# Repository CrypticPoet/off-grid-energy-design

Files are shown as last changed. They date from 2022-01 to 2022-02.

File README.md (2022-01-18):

# Off Grid Energy Design

This repository is for documentation of the Off Grid Energy system design process.

## Process Roadmap

-   [x] Requirements
-   [ ] Specifications
-   [ ] Design

### Specification Components Checklist
- [x] Solar Panels
- [x] Batteries
- [x] Inverter
- [x] Solar Charge Controller
- [x] Solar Panel Mounts
- [x] Battery Monitor
- [x] Backup Generator
- [x] Biogas Plant
- [x] Safety Measures
- [x] Connecting Wires

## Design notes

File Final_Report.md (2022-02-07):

---
title: "Sunergy Final Report"
author: "Tribe E (EE > MT)"
keywords:
   - renewable
   - solar
   - off-grid
   - sustainable
---

# ELP305 Design and Systems Laboratory
## Semester 2, 2021-2022 
### Tribe E

# SUNERGY: Final Report

| ID | v4.0 |
| :--- | :--- |
| Tribe | Tribe E |
| Approved By | Vishal Asthana (TC) / 01-02-2022 / 2200 Hrs |
| Contact for Queries | Mihir Okte (mt1190703@iitd.ac.in) |
| Submitted to | Prof. Subrat Kar, Course Coordinator \| ELP305: Design and Systems Laboratory |
| Date of Submission  | 02-02-2022 |

**NOTE:** The GitHub repository that our tribe is using is linked [here](https://github.com/CrypticPoet/off-grid-energy-design)

## Table of Contents
- [1. Authors](#1-authors)
- [2. Documentation Statistics](#2-documentation-statistics)
	- [2.0.1. Text Statistics](#201-text-statistics)
	- [2.0.2. Readability indices](#202-readability-indices)
- [3. Preamble](#3-preamble)
	- [3.0.1. List of Abbreviations](#301-list-of-abbreviations)
	- [3.0.2. List of Tables](#302-list-of-tables)
	- [3.0.3. List of Figures](#303-list-of-figures)
- [4. Abstract](#4-abstract)
- [5. Aim](#5-aim)
- [6. Scope](#6-scope)
- [7. Requirements](#7-requirements)
	- [7.1. Base Setup](#71-base-setup)
	- [7.2. Basic Requirements](#72-basic-requirements)
	- [7.3. Technical Requirements](#73-technical-requirements)
- [8. Specifications](#8-specifications)
	- [8.1. Electrical Specifications](#81-electrical-specifications)
		- [8.1.1. Battery](#811-battery)
			- [8.1.1.1. Luminous Red Charge RC 18000 150 Ah Battery](#8111-luminous-red-charge-rc-18000-150-ah-battery)
		- [8.1.2. Backup Generator](#812-backup-generator)
		- [8.1.3. Hybrid Solar Inverter (Built in Solar Charge Controller)](#813-hybrid-solar-inverter-built-in-solar-charge-controller)
			- [8.1.3.1. 3KVA/ 36 V Off Grid Solar Inverter](#8131-3kva-36-v-off-grid-solar-inverter)
		- [8.1.4. Solar Charge Controller](#814-solar-charge-controller)
			- [8.1.4.1. Sizing](#8141-sizing)
		- [8.1.5. High Efficiency Solar Panels](#815-high-efficiency-solar-panels)
		- [8.1.6. Wires](#816-wires)
			- [8.1.6.1. Solar DC Cable](#8161-solar-dc-cable)
			- [8.1.6.2. Household connection wires](#8162-household-connection-wires)
		- [8.1.7. Safety Measures](#817-safety-measures)
			- [8.1.7.1. AC Circuit Breaker](#8171-ac-circuit-breaker)
			- [8.1.7.2. DC Circuit Breaker](#8172-dc-circuit-breaker)
			- [8.1.7.3. DC Surge Protection Device](#8173-dc-surge-protection-device)
			- [8.1.7.4. Porcelain Fuse](#8174-porcelain-fuse)
		- [8.1.8. MC4 Connectors](#818-mc4-connectors)
			- [8.1.8.1. MC4 Solar Panel Connectors](#8181-mc4-solar-panel-connectors)
			- [8.1.8.2. 4 in 1 T4 Connector](#8182-4-in-1-t4-connector)
	- [8.2. Mechanical Specifications](#82-mechanical-specifications)
		- [8.2.1. Solar Panel Mounts](#821-solar-panel-mounts)
- [9. Design](#9-design)
	- [9.1. CAD/Assembly](#91-cadassembly)
	- [9.2. Wiring Diagram](#92-wiring-diagram)
- [10. Cost Analysis](#10-cost-analysis)
- [11. Reuse of Materials](#11-reuse-of-materials)
- [12. Project Management](#12-project-management)
	- [12.1. Gantt Chart and CPM](#121-gantt-chart-and-cpm)
	- [12.2. Resources Chart](#122-resources-chart)
	- [12.3. Work Packages](#123-work-packages)
- [13. Attributions](#13-attributions)
- [14. References](#14-references)

---

## 1. Authors
| S. No. | Name | Email id | Role | Performance |
| -----: | :--- | :---: | :--- | :---: |
| 1. | Vishal Asthana | ee1191083@iitd.ac.in | Tribe Coordinator | 1.0 |
| 2. | Ritvik Gupta | mt1190512@iitd.ac.in | Documentation Sub Tribe Coordinator | 1.0 |
| 3. | Shubham Jangra | ee1190529@iitd.ac.in | Solar Panels Sub Tribe Coordinator | 1.0 |
| 4. | Shailendra Thenua | ee1190522@iitd.ac.in | Battery and Inverter Sub Tribe Coordinator | 1.0 |
| 5. | Mihir Okte | mt1190703@iitd.ac.in | CAD Design Sub Tribe Coordinator | 1.0 |
| 6. | Shloka Bhuwalka | ee1190527@iitd.ac.in | Wiring and LTSpice Sub Tribe Coordinator | 1.0 |
| 7. | Uddhav Goel | ee1190540@iitd.ac.in | Project Management Sub Tribe Coordinator | 1.0 |
| 8. | Abhishek Kumar | ee1190456@iitd.ac.in | Member | 1.0 |
| 9. | Abhishek Kumar | ee1190457@iitd.ac.in | Member | 1.0 |
| 10. | Aditya Verma | mt1190672@iitd.ac.in | Member | 0.8 |
| 11. | Ahsan Kamal | mt6190740@iitd.ac.in | Member | 1.0 |
| 12. | Akash Agrawal | ee3190006@iitd.ac.in | Member | 1.0 |
| 13. | Aman Yadav | mt1200786@iitd.ac.in | Member | 0.6 |
| 14. | Amit Kumar | mt6190744@iitd.ac.in | Member | 1.0 |
| 15. | Anirudh Singh Chauhan | ee1191072@iitd.ac.in | Member | 1.0 |
| 16. | Ankit Kumar Meena | ee3190555@iitd.ac.in | Member | 1.0 |
| 17. | Anshuman Panda | mt1190463@iitd.ac.in | Member | 1.0 |
| 18. | Anurag Sharma | mt6190745@iitd.ac.in | Member | 1.0 |
| 19. | Ayush Joshi | ee1190486@iitd.ac.in | Member | 1.0 |
| 20. | Ayush Meena | ee1190468@iitd.ac.in | Member | 0.6 |
| 21. | Bhargav Halipeth | ee3190562@iitd.ac.in | Member | 1.0 |
| 22. | Govind Patidar | ee1190478@iitd.ac.in | Member | 0.0 |
| 23. | Guruvu Surya Sai Prakash | ee1190481@iitd.ac.in | Member | 1.0 |
| 24. | Harshit Nekela | mt1190693@iitd.ac.in | Member | 1.0 |
| 25. | Het Patel | ee1190484@iitd.ac.in | Member | 1.0 |
| 26. | Manisha Chaudhary | ee1190494@iitd.ac.in | Member | 1.0 |
| 27. | Mohit Yadav | ee3190582@iitd.ac.in | Member | 0.5 |
| 28. | Ohm V | ee1190499@iitd.ac.in | Member | 1.0 |
| 29. | Pragya Dhakar | mt6190756@iitd.ac.in | Member | 1.0 |
| 30. | Prasoon Bajpai | mt6190824@iitd.ac.in | Member | 1.0 |
| 31. | Prateek Sinha | mt1190716@iitd.ac.in | Member | 1.0 |
| 32. | Rajdeep Das | mt1190718@iitd.ac.in | Member | 1.0 |
| 33. | Ronak Choudhary | ee3190597@iitd.ac.in | Member | 1.0 |
| 34. | Sahil Raj | mt1190723@iitd.ac.in | Member | 1.0 |
| 35. | Satyam Sharma | ee1190521@iitd.ac.in | Member | 0.5 |
| 36. | Shashank Nehra | ee1190523@iitd.ac.in | Member | 1.0 |
| 37. | Shivam Garg | ee1190600@iitd.ac.in | Member | 1.0 |
| 38. | Shivam Gupta | ee1190601@iitd.ac.in | Member | 1.0 |
| 39. | Shivang Garde | ee1180501@iitd.ac.in | Member | 1.0 |
| 40. | Shivani Singh | ee1190525@iitd.ac.in | Member | 1.0 |
| 41. | Siddhant Sharma | ee1190531@iitd.ac.in | Member | 1.0 |
| 42. | Suvam Paul | ee1190536@iitd.ac.in | Member | 1.0 |
| 43. | Tanmay Kumar | ee1190538@iitd.ac.in | Member | 1.0 |
| 44. | Tushar Singh | ee1190539@iitd.ac.in | Member | 1.0 |
| 45. | Udit Dahiya | ee3190852@iitd.ac.in | Member | 1.0 |
| 46. | Vaibhav Verma | ee1190543@iitd.ac.in | Member | 1.0 |
| 47. | Vansh Gupta | ee1190143@iitd.ac.in | Member | 1.0 |
| 48. | Yash Pal Singh | ee1190548@iitd.ac.in | Member | 1.0 |
| 49. | Yug Garg | ee3190607@iitd.ac.in | Member | 1.0 |

**Table 1:** List of Authors

---

## 2. Documentation Statistics
#### 2.0.1. Text Statistics
<!-- To be changed -->

| Word Count | # unique words | # repeated words | # sentences | # characters | # characters w/o spaces | # syllables |
| --- | --- | --- | --- | --- | --- | --- |
| 7530 | 2284 | 5246 | 216 | 71422 | 49169 | 13615 |

| Avg # words per sentence | Avg # characters per sentence | Avg # characters per word | Avg # syllables per word |
| --- | --- | --- | --- |
| 35 | 330.6 | 9.5 | 1.80 |

**Table 2:** Text Statistics

The above results were obtained using https://wordcounter.net/.

#### 2.0.2. Readability indices
<!-- To be changed -->

| Readability Index | Score | Can be easily understood by |
| :--- | :---- | :--- |
| Flesch Reading Ease score | 58 | 10th to 12th grade students |
| Dale-Chall Readability score | 8.8 | 11th or 12th grade students |
| Flesch-Kincaid Grade level | 7 | 7th grade students |
| The Coleman-Liau Index | 14 | Undergraduate students |
| Automated Readability Index  | 11 | 10th grade students |
| SMOG Formula score | 12 | 7th grade students |
| Spache Readability score | 4 | 4th grade students |

**Table 3:** Readability indices

The above scores were obtained using Visual Studio Code extension called Readability Check by jemcclin.

---

## 3. Preamble

#### 3.0.1. List of Abbreviations

| S. No. | Abbreviation  | Stands For |
| :----: | :---: | :--- |
| 1. | AC | Alternating Current |
| 2. | BIS | Bureau of Indian Standards |
| 3. | CAD | Computer Aided Design |
| 4. | DC | Direct Current |
| 5. | ETP | Electrolytic Tough Pitch |
| 6. | HRFR | Heat Resistant Flame Retardant |
| 7. | IMP | Current at Maximum Power |
| 8. | IP | Ingress Protection |
| 9. | LED | Light Emitting Diode |
|  10. | MPPT | Maximum Power Point Tracking |
|  11. | misc | Miscellaneous |
|  12. | MCB | Miniature Circuit Breaker |
|  13. | MC4 Connector | Multi-Contact 4 mm diameter contact pin Connector |
|  14. | PERC | Passivated Emitter and Rear Contact |
|  15. | PWM | Pulse Width Modulation |
|  16. | PC | Personal Computer |
|  17. | PA | Polyamide |
|  18. | PPO | Polyphenylene Oxide |
|  19. | UV | UltraViolet |
|  20. | VMP | Voltage at Maximum Power |
|  21. | Voc | Voltage at Open Circuit |

#### 3.0.2. List of Tables

| S. No. | Table |
| :----: | :--- |
| 1. | [**Authors**](#authors) |
| 2. | [**Documentation Statistics**](#documentation-statistics) |
| 3. | [**Readability indices**](#readability-indices) |
| 4. | [**Power Requirements**](#basic-requirements) |
| 5. | [**Battery**](#battery) |
| 6. | [**Backup Generator**](#backup-generator) |
| 7. | [**Hybrid Solar Inverter**](#hybrid-solar-inverter-built-in-solar-charge-controller) |
| 8. | [**Solar Charge Controller**](#solar-charge-controller) |
| 9. | [**High Efficiency Solar Panels**](#high-efficiency-solar-panels) |
|  10. | [**Solar DC Cable**](#solar-dc-cable) |
|  11. | [**Household connection wires**](#household-connection-wires) |
|  12. | [**AC Circuit Breakers**](#ac-circuit-breaker) |
|  13. | [**DC Circuit Breakers**](#dc-circuit-breaker) |
|  14. | [**DC Surge Protection Device**](#dc-surge-protection-device) |
|  15. | [**Porcelain Fuse**](#porcelain-fuse) |
|  16. | [**MC4 Solar Panel Connectors**](#mc4-solar-panel-connectors) |
|  17. | [**4 in 1 T4 Connector**](#4-in-1-t4-connector) |
|  18. | [**Solar Panel Mounts**](#solar-panel-mounts) |
|  19. | [**Cost Analysis**](#cost-analysis) |

#### 3.0.3. List of Figures

| S. No. | Figures |
| :----: | :--- |
| 1. | [**Mindmap for Requirements**](#reqs_mm) |
| 2. | [**Mindmap for Specifications**](#specs_mm) |
| 3. | [**Luminous Red Charge RC 18000 150 Ah Battery**](#luminous-red-charge-rc-18000-150-ah-battery) |
| 4. | [**Off Grid Solar Inverter**](#3kva-36-v-off-grid-solar-inverter) |
| 5. | [**Solar Panels**](#high-efficiency-solar-panels) |
| 6. | [**Solar DC Cables**](#solar-dc-cable) |
| 7. | [**Household Connection Wires**](#household-connection-wires) |
| 8. | [**AC Circuit Breaker**](#ac-circuit-breaker) |
| 9. | [**DC Circuit Breaker**](#dc-circuit-breaker) |
|  10. | [**DC Surge Protection Device**](#dc-surge-protection-device) |
|  11. | [**Porcelain Fuse**](#porcelain-fuse) |
|  12. | [**MC4 Solar Panel Connectors**](#mc4-solar-panel-connectors) |
|  13. | [**4 in 1 T4 Connector**](#4-in-1-t4-connector) |
|  14. | [**Solar Panel Mounts**](#solar-panel-mounts) |
|  15. | [**Mindmap for Design**](#design) |
|  16. | [**Front View of Designed House**](#front) |
|  17. | [**Side View of Designed House**](#side) |
|  18. | [**Top View of Designed House**](#top) |
|  19. | [**Orthographic View of Designed House**](#orthographic) |
|  20. | [**Isometric View of Solar Panels 1**](#panel_view) |
|  21. | [**Isometric View of Solar Panels 2**](#panel_view) |
|  22. | [**Isometric View of Inverter 1**](#inverter_view) |
|  23. | [**Isometric View of Inverter 2**](#inverter_view) |
|  24. | [**Isometric View of Battery 1**](#battery_view) |
|  25. | [**Isometric View of Battery 2**](#battery_view) |
|  26. | [**Wiring Diagram**](#wiring) |
|  27. | [**Gantt Chart**](#gantt) |
|  28. | [**Work Breakdown Structure**](#work_breakdown) |
|  29. | [**Resources**](#resources) |
|  30. | [**Work Breakdown: Assignment of Work**](#assign_work) |
|  31. | [**Work Breakdown: Project Management**](#proj_manage) |
|  32. | [**Work Breakdown: CAD Model**](#cad_model) |
|  33. | [**Work Breakdown: Circuit Design**](#circuit) |
|  34. | [**Work Breakdown: Specifications**](#specs) |
|  35. | [**Work Breakdown: Documentation**](#docs) |

---

## 4. Abstract
The necessity for increased power generation is unavoidable since the world's electricity consumption rises on a regular basis. As a result, we need renewable energy resources which can meet electrical power demand up to a large fraction of total demand. In this report we are designing a cost-effective self-sustainable electrical system using the available solution in the market to meet the general electrical requirements of an Indian Household. Solar energy is used as major renewable energy source as it is versatile compared to other renewable sources, easy and feasible to convert in electrical form.

---

## 5. Aim

In this project we aim to design a cost-effective off-grid self sustainable electrical system using the available products in market. In our final report we revisit our previously submitted requirements and specifications and adjust them accordingly to match the final design cycle of the project.  Here we try to compile all the previous product cycles in order to deliver the final design of the electrical system alongside it's cost analysis and vendor information to ensure smooth installation.

---

## 6. Scope

In this hustling daily routine, many people tend to resort to a house in the forest for peace of mind. Also, there is a large part of India where electricity has not reached yet. This is an off-grid solution for daily energy needs such as electricity and heat energy. 

We will be using solar panels for electricity along with a diesel/petrol generator for backup in order to meet the electricity needs. A biogas plant for heat energy needs will also be used as a backup.

We will be covering the technical aspects of the components involved such as the electrical specifications of all components needed for a fully functional solar power setup, power output of fuel generator. We will also cover the physical/mechanical specifications such as dimensions etc. Apart from this, it also includes supplier information, 3D Diagrams of setup/assembly and cost analysis such as price of components along with installation charges.

The solution has been made keeping in mind a specific geographical location (A forest in eastern coast of India) which has ample fuel wood, natural water sources nearby, sufficient amount of biomass (twigs, leaves fallen on ground) nearby for utilizing in biogas plant. It is designed assuming the energy needs of a family of 6 members. It will not be an optimal solution if the family has more than 6 members or there is a greater number of adults in the family than assumed. (Average energy needs of an adult are more than that of kids). Energy requirements for appliances such as television, refrigerator, air-conditioner etc. are not included in the analysis as these will be considered as “luxury items” considering the location to be an isolated forest. The supplier information and component availability is mentioned keeping India in mind. Hence, the components might not be available outside India. It has provisions if there is lack of proper sunlight for a few days, but prolonged periods of improper sunlight will lead to relying on fuel generator for energy demands. It has been assumed that there will not be any kind of hindrance in the path of sunlight incident on solar panels.

---

## 7. Requirements

In the following section, we give a brief on various traits that our off-grid living solution must possess. We also jot down the various requirements that will be needed to ensure our proposed solution is as efficient and trustworthy as possible.

<p align="center" id = "reqs_mm">
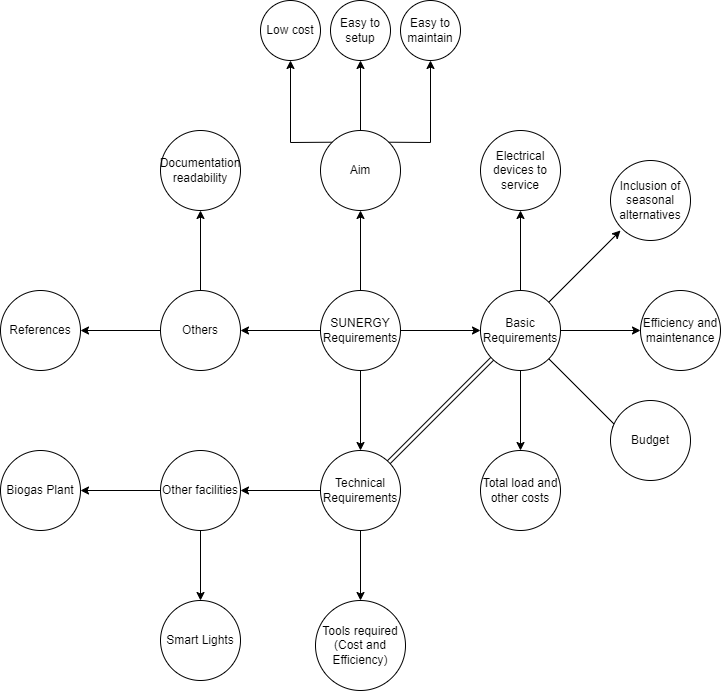
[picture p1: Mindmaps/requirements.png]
Mindmap for Requirements
	  
	 <figcaption align="center"><b>Figure 1:</b> Mindmap for Requirements</figcaption>
</p>

---

### 7.1. Base Setup

One of the main requirements for the system is that it is reasonably easy to set up so that minimum technical assistance is required for the same, and the house owner can perhaps even set it up himself.
These requirements require the system to be:

-   **Easy to implement**: The system should be easy to implement so that any person with little or no technical experience can implement and install the system by following simple instructions. The system also needs to be easy to repair so that there are minimum power cuts.
-   **Low maintenance**: The system needs to require low maintenance so that the user does not have to get it serviced frequently. If possible, it should be such that the users can themselves service it.
-   **Set-up time**: The system should be able to be set up within a short duration of time (3-4 days) to avoid any inconvenience in the form of power breaks to the users during the setup.
-   **Easy to Remove**: The system should be easy to remove so that the user can remove the setup if they want to relocate to a new location. For this, the system should also allow easy transportation over long distances so that the user can take it with themselves
-   **Long-term sustenance**: Should sustain itself for long periods of time even in the absence of production (no solar production during winters).
-   **Backup Generator**: Need in cases of emergency, high power usage situations, and 2nd option for achieving the above goal (long-term sustenance).

---

### 7.2. Basic Requirements

Some of the basic user requirements are:

1. **Accommodation**: The energy generated should be able to satisfy the needs of a family of six.

2. **Power Requirements**: The daily power requirement is approximately 24-25 kWh. The explanation for the same can be seen as follows:

| S. No. | Appliance | Number of Appliances | Power Consumed by Each | Daily Time Consumption | Total Energy Consumed | Explanation |
| --- | --- | --- | --- | --- | --- | --- |
| 1 | Tube Light | 8 | 0.02kW | 8 Hours | 0.02\*4\*8=0.64kWh | Assuming, on average, 4 lights out of 8 are ON for 8 hours. |
| 2 | LED Bulbs | 4 | 0.04kW | 6 Hours | 0.04\*3\*6=0.72kWh | Assuming, on average, 3 lights out of 4 are ON for 6 hours. |
| 3 | Ordinary ceiling fan | 6 | 0.075kW | 10 Hours | 0.075\*4\*10=3kWh | Assuming, on average, 4 fans out of 6 are ON for 8 hours.  Only in Summers |
| 4 | Induction Stove | 1 | 1.8kW | 2 Hour | 1.8\*1\*2=3.6kWh | |
| 5 | Water Heater | 2 | 1.5kW | 1 Hour | 1.5\*2\*1=3kWh | Only in Winters |
| 6 | Laptop Adapater | 1 | 0.045W | 10 Hours | 0.045\*1\*10=0.45kWh  | |
| 7 | Miscellaneous (e.g TV 50 inch 0.1kW, PC 0.2kW) | | | | 1kWh | Assuming extra consumption to be 1kWh per day. |
| Daily power requirement | Summers//Winters | | | | 9.41//9.41 kWh ± 10%  |

**Table 4:** Power Requirements

3. **Budget**: The cost of manufacturing should not be more than &#8377;3,00,000.

4. **Backup**: In case of any system failure, there must be a fuel generator strong enough to provide backup for the basic energy requirements.

5. **Water Requirements**: The energy should sustain the operation of bore pumps to satisfy the water requirements of the house.

6. **Season**: There should be suitable alternatives to meet the energy requirements with changing seasons such as substitutes for solar panels during the winter season.

7. **Maintenance**: The system should require low maintenance in terms of system longevity. This should also be easy-to-handle by the residents themselves.

8. **Efficiency**: The batteries used to store energy should be efficient in order to ensure longer periods of usage. The appliances can also be used in an energy saver mode.

9. **Safety**: There must be fuses and master controller or circuit breakers (MCB) in order to ensure safety in case of fluctuations or malfunction.

10. **Monitoring**: The system should have a provision for monitoring the total energy consumed by all major appliances.

11. **Remote Access**: The system should be equipped with a remote accessing facility of solar panels as well as the appliances.

---

### 7.3. Technical Requirements

Various technical apparatus and tools required to achieve our goal are:

1. **Solar Panels**: An assembly of photo-voltaic cells mounted and connected to each other used to harness solar energy and convert it into electrical energy. The electricity produced by solar panels is DC in nature. Some factors characteristic of a good solar panel are low price, high efficiency, low-temperature coefficient.

2. **Batteries**: Deep cycle batteries are used in order to store energy produced by the solar panels during the day to use during the night. In order to have a long battery life, we wish to have a battery with a larger number of charge/recharge cycles.

3. **Inverter**: Solar panels generate DC electricity which needs to be converted to AC electricity needed by many common household appliances which are achieved by using an inverter. We wish to have an inverter that is cheap and provides high efficiency in converting DC to AC with minimal power losses.

4. **Mounting apparatus**: Solar panels are usually connected to each other and then subsequently mounted either on the roof or on the ground. The panels must be mounted so as to ensure cooling airflow and in a manner where maximum sunlight is available to the panels throughout the day.

5. **Charge Controllers**: Charge controllers are used to control the amount of current fed into the battery by the solar panels.This ensures the batteries are not overcharged during the day and don't leak current back to the panels during the night. There are two types of charge controller devices available - PWM and MPPT of which MPPT though more expensive is upto 30% more efficient than PWM charge controllers.

6. **Battery Monitor**: This meter would allow us to get an idea of how much power is being generated, how much amount we are saving by using solar panels and helps monitor which appliances use more power to manage energy utility.

7. **Backup Generator**: In case of off-grid systems backup power supply like a generator can serve as an alternate power supply in case of cloudy days, high demand or other unforeseen circumstances. The environmental impact of the generator could be reduced by using alternative fuels like biodiesel.

8. **Disconnects**: These are manual switches that enable us to cut off the power supply to and from the inverter in case of maintenance. This prevents current from flowing beyond the switch to some damaged component.

9. **Smart Lights**: Smart lights can be used to track Daytime and thus switching on/off lights at necessary places accordingly. This would allow us to smartly switch off electrical appliances not being used in order to save energy.

10. **Wires**: Insulated copper or aluminum wires needed to connect various electrical components

11. **Bio Gas plant**(optional): A biogas plant can be set up to harness energy out of the biodegradable waste that is produced in the household. This can later be used in the form of cooking gas or processed through a biogas generator for an alternative electricity source.

---

## 8. Specifications

In the following section, we give a brief on various specifications of the components that we will be using in our off-grid living solution. We also mention their properties and why we have chosen them along with the best quotation available for each component.

<p align="center" id="specs_mm">
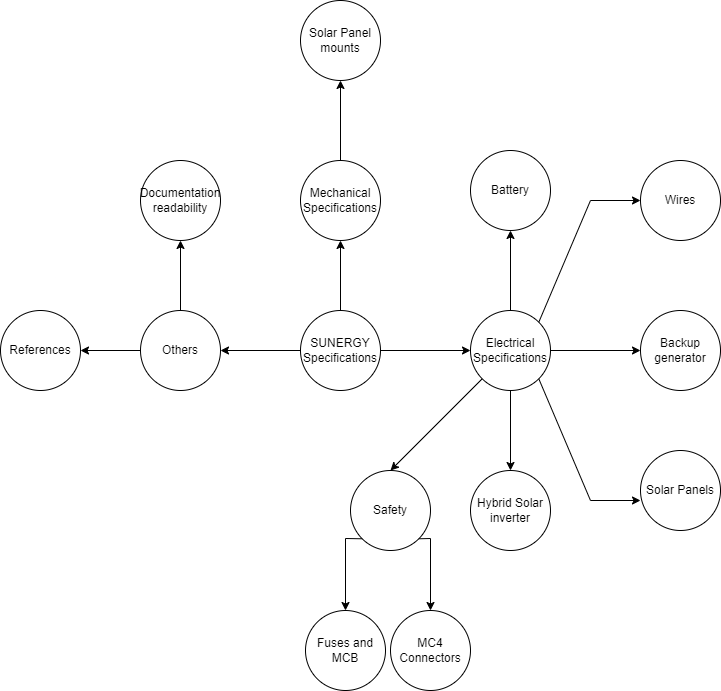
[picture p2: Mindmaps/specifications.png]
Mindmap for Specifications
	  
	 <figcaption align="center"><b>Figure 2:</b> Mindmap for Specifications</figcaption>
</p>

---

### 8.1. Electrical Specifications
#### 8.1.1. Battery
##### 8.1.1.1. Luminous Red Charge RC 18000 150 Ah Battery

battery
<figcaption><b>Figure 3:</b> Luminous Red Charge RC 18000 150 Ah battery</figcaption>

- For heavy-duty application with excellent overcharge tolerance, superior performance during long frequent power cuts, and minimum maintenance
-  fast battery charging with adaptive battery charging control technology

| Specifications | Value |
| --- | --- |
| Brand | Luminous |
| Nominal Voltage | 12V |
| Rated Capacity(at room temp.) | 150 ah (at room temp.) |
| Protections | Dust & waterproof with heavy plastic body |
| Charging Current(Boost mode) | 15.10A(starting), 7.60A(finishing) |
| Charging Current (Trickle mode) | 504 mA(max), 126 mA(min) |
| Weight | 53.30 Kg (28.5 Kg dry weight) (+/- 5%) |
| Dimensions | 50.2 $\times$ 44 $\times$ 19.1 cm (L $\times$ W $\times$ H) |
| Electrolyte Volume | 20L (+/-5%) |
| Water Level Indicators | 6 |
| Cost | &#8377;12150 X 3 = &#8377;36450 |

**Table 5:** Specifications of Battery

---

#### 8.1.2. Backup Generator

The generator size should be of 1kW. In our system, generator will mostly be needed during winter when there is a lack of solar energy production. Since this is a backup system the below power consumed is assumed to be calculated under minimal load when running backup generator.

Total Instantaneous Power Consumed = 0.020*2(light)+0.5(misc) = 0.58kW

**Note**: Here the misc includes PC, stove and other appliances that we might/might not use under emergency situation. The generator should be able to run under the above conditions for 9hr(which is minimum requirement for overnight functionality). Spare fuel should always be kept in case of emergencies. 

| Specification | Value |
| --- | --- |
| Manufacturer | Generic |
| Fuel | Petrol |
| Consumption | 1L/hr under full load |
| Capacity | 10L |
| Rated voltage | 220V+-15 |
| Peak output power | 1kVA |
| Weight | 30kg |
| Cost | &#8377;22,900 |
| Size | 1kW |

**Table 6:** Specifications of Backup Generator

[Product Link](https://www.indiamart.com/proddetail/1-kva-portable-petrol-generator-23901047630.html)

---

#### 8.1.3. Hybrid Solar Inverter (Built in Solar Charge Controller)
##### 8.1.3.1. 3KVA/ 36 V Off Grid Solar Inverter

battery
<figcaption><b>Figure 4:</b> 3KVA/ 36 V Off Grid Solar Inverter</figcaption>
<br>

Luminous Solar Hybrid Inverter 3kVA/36 is an off grid hybrid solar inverter which allows smart management of Solar Power, Grid Supply and Battery to deliver uninterrupted power for all electrical appliances. It comes built in with an MPPT technology based Solar Charge Controller that converts solar energy into electricity and stores power. 
-   3 kva system with 3500 watt solar panel support
-   super efficient as low conversion loss from battery
-   LCD Battery Monitoring system with display parameters such as Input Power, Output power load, battery health, battery percentage, Overload, MCB Trip and Over Temperature Protection
-   Surge warnings, safety alarms and troubleshooting Fault Codes 
-   BIS certified solar inverter and IP-21 protection level.
-  MCB protection in the case of any short circuit
-  Comprehensive protection against short-circuit, reverse polarity, battery overload etc.

| Specification | Value |
| --- | --- |
| Brand | Luminous |
| Rated Power | 3kVA |
| Waveform | Pure sine wave |
| Output Voltage Regulation | 230VAC $\pm$ 2% |
| Output Frequency | 50 Hz |
| Battery Bank Voltage | 36 V(3x12V batteries) |
| Input Voltage Mains Mode | 180-260 VAC |
| Output Voltage Distortion(THD) | <=3% |
| Nominal Output Current from UPS | 11 A |
| Operating Temperature | 0 - 45<sup>.</sup>C |
| Input Protection | 32A MCB |
| Battery Charging Current | 14A, 17A, 21A |
| Max. Relative Humidity @25<sup>.</sup>C | upto 95% |
| Dimensions | D x W x H (mm) 300 x 417 x 452 |
| Net Weight | 32.5 kg |
| Cost | &#8377;39,950 |

**Table 7:** Specifications of Hybrid Solar Inverter

#### 8.1.4. Solar Charge Controller

Charge controllers are used to control the amount of current fed into the battery by the solar panels. This ensures the batteries are not overcharged during the day and don't leak current back to the panels during the night. So, Solar Charge Controller must be compatible with solar panel and the battery bank. Our Hybrid inverter comes built in with an MPPT Charge controller which is more efficient at DC Conversion compared to older PWM technology.

##### 8.1.4.1. Sizing
Sizing of a controller depends on three factors
- Solar panel array’s maximum open-circuit voltage (Voc)
- Total Power rating of Solar panel array
- Battery Bank Voltage

Specifications of the in-built charge controller

| Specification | Value |
| --- | --- |
| Brand | Luminous |
| Type | MPPT |
| Nominal Battery Charging Current | 91A$\pm$ 2A |
| Maximum Battery Charging Current | <=100A$\pm$ 10A |
| Maximum PV Array Power | 3.5 kW |
| Maximum PV Input Current(Imp) | 38A |
| Solar Input Voltage VMP | 60V - 120V |
| Solar Input Voltage VOC | 75V - 150V |

**Table 8:** Specifications of Solar Charge Controller

[Product Link](https://www.urbanurja.com/products/luminous-solarverter-pro-pcu-3-kva-36v-mppt-solar-inverter#)

---

#### 8.1.5. High Efficiency Solar Panels

Solar panels collect clean renewable energy in the form of sunlight and convert that light into electricity which can then be used to provide power for electrical loads. 

The panels which we're using, are based on [mono PERC cells](https://regenpower.com/news/why-choose-mono-perc-panels-rooftop-solar/), which results into higher electricity generation due to higher light absorption per unit area, when compared to traditional panels.
 
It also paves the way for more power output per panel, which means less number of panels are required for a given power requirement. It means less expenditure for 
[panel mounts](https://encrypted-tbn0.gstatic.com/images?q=tbn:ANd9GcSWhB7u8DxJiUJTM2uH5U-6Ml3h3SoByqJd8g&usqp=CAU).
We'll be using 4 such panels in our system.


<figcaption><b>Figure 5:</b>  Solar Panels</figcaption>

| Specification (Single panel) | Value |
| --- | --- |
| Cost | &#8377;20,000 |
| Operating Voltage | 24V |
| Dimensions | 6.9ft X 3.4ft |
| Manufacturer | Loom Solar |
| Rated Output Power (Peak) | 440W |
| Output Voltage at max. power | 42V |
| Output Current at max. power | 10.5A |

**Table 9:** Specifications of High Efficiency Solar Panels

*Above electrical data is for, Irradiance: 1000W/m² and Cell Temperature:25°C*

[Product Link](https://www.loomsolar.com/products/loom-solar-panel-shark-super-high-efficiency-module)

---

#### 8.1.6. Wires
##### 8.1.6.1. Solar DC Cable
DC Solar Panel cables are required to connect the array of solar panels in series with each other and then carry the output DC Current to the Solar Charge Controller.

When choosing DC Solar Panel wires, some things should be kept in mind
- The wires should be of sufficient diameter to ensure that no overheating occurs
- The wires should be of adequate current rating
- UV resistance to ensure longevity


<figcaption><b>Figure 6:</b> Solar DC Cables</figcaption>

| Specification | Value |
| --- | --- |
| Brand | Microtek |
| Current carrying capacity | 80 A |
| Cross Sectional Area | 10 mm² |
| Length | 15m Red and 15m Black |
| Cost | &#8377;1990 |

**Table 10:** Specification of Solar DC Cable

[Product Link](https://www.amazon.in/Microtek-Solar-Cable-Protected-15Meter/dp/B08BBYX28X/)

#####  8.1.6.2. Household connection wires
Connecting wires would be used to connect different appliances in the energy grid.  Hence they should be able to carry high current and be well insulated.

connecting wires
<figcaption><b>Figure 7:</b> Household connection Wire</figcaption>

| Specification | Value |
| --- | --- |
| Brand | Havells |
| Length | 90 m |
| Cross-sectional area | 2.5 sq mm |
| Current carrying capacity | 28 A |
| Voltage Grade | 1100 V |
| Insulation material | HRFR PV |
| Conductor material | ETP Grade Annealed Copper |
| Cost | &#8377;2,871 |

Table 11 : Specification of Household Connection Wires

[Product Link](http://dl.flipkart.com/dl/havells-hrfr-pvc-2-5-sq-mm-black-90-m-wire/p/itmbcd2c1b016975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)

---

#### 8.1.7. Safety Measures

##### 8.1.7.1. AC Circuit Breaker
 
A separate AC Breaker between the AC Input and Inverter is required to ensure tha the inverter can be securely disconnected during maintenance and secured from AC Input over current


<figcaption><b>Figure 8:</b> AC Circuit Breaker</figcaption>

| Specification  | Value |
| --- | --- |
| Brand | Siemens |
| Current Rating | 63 A |
| No. of Poles | 4 |
| Dimensions | 7.1 cm X 7 cm X 9 cm |
| Weight | 660 g |
| Material | Polycarbonate |
| Color | White |
| Cost | &#8377;1500 |

**Table 12:** Specification of AC Circuit Breakers

 [Product Link](https://www.amazon.in/Siemens-Pole-White-1-Piece-5SL64637RC/dp/B01D4QL6RC)

##### 8.1.7.2. DC Circuit Breaker

A DC Circuit breaker between the Solar Panels and Inverter is required for disconnecting the solar panels safely for maintenance or replacement. The Circuit breaker also protects the inverter from over current damage


<figcaption><b>Figure 9:</b> DC Circuit Breaker</figcaption>

| Specification | Value |
| --- | --- |
| Brand | FEEO |
| Circuit Breaker Type | Standard |
| Current Rating | 63 A |
| No. of Poles | 2 |
| Voltage | 800 V (DC) |
| Dimensions | 7.1 cm X 3.6 cm X 8 cm |
| Cost | &#8377;999 |

**Table 13:** Specification of DC Circuit Breaker

[Product Link](https://www.amazon.in/FEEO-63A-Double-Pole-MCB/dp/B01LF8E0T2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)

##### 8.1.7.3. DC Surge Protection Device

The DC Surge Protector protects the inverter and panels from any unforeseen voltage surges in instances such as Lightning strikes


<figcaption><b>Figure 10:</b> DC Surge Protection Device</figcaption>

| Specification | Value |
| --- | --- |
| Brand | Kenbrook Solar |
| Overvoltage Rating | 600V |
| No. of Poles | 2 |
| Dimension | 9 cm X 6 cm X 3.5 cm |
| Weight | 245 g |
| Cost | &#8377;799 |

**Table 14:** Specification of DC surge protection device

[Product Link](https://www.amazon.in/Kenbrook-Solar-Elmak-Protection-Device/dp/B09NTQDJGP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)

#####  8.1.7.4. Porcelain Fuse


<figcaption><b>Figure 11:</b> Porcelain Fuse</figcaption>

| Specification | Value |
| --- | --- |
| Brand | Anchor |
| AC Adapter Current | 32 A |
| Voltage | 415 V |
| Material | Ceramic |
| Dimensions | 10 cm X 5 cm X 5 cm |
| Cost | &#8377;185 |

**Table 15:** Specification of porcelain fuse

[Product Link](https://www.amazon.in/Anchor-9311-Porcelain-Pilot-Ivory/dp/B00V4VJ7IK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)

---

#### 8.1.8. MC4 Connectors
##### 8.1.8.1. MC4 Solar Panel Connectors

MC4 Connectors are required for a safe and convenient connection between the solar panel arrays.   
The Kenbrook Solar MC4 Connectors are UV resistant, waterproof and anti-flame boasting an estimated life of upto 25 years and thus require minimum maintenance.


<figcaption><b>Figure 12:</b> MC4 Solar Panel Connectors</figcaption>

| Specification | Value |
| --- | --- |
| Brand | Kenbrook |
| Material | Copper (Tin Plated) \| PPO + PA (Outer Covering) |
| Dimensions | 6 x 4 x 2 cm |
| Quantity | 10 Male + Female MC4 Connectors |
| Cost | &#8377;449 |

**Table 16:** Specification of MC4 solar panel connectors

[Product Link](https://www.amazon.in/Kenbrook-Solar-Connector-Panel-Connection/dp/B08VNW7DLP/)

##### 8.1.8.2. 4 in 1 T4 Connector

T4 Connector is required to connect the 2x4 parallel solar panel array to the solar charge controller. The T4 connector also comes with UV Resistance, anti flame and water resistance


<figcaption><b>Figure 13:</b> 4 in 1 T4 Connector</figcaption>

| Specification | Value |
| --- | --- |
| Brand | Kenbrook |
| Material | Copper (Tin Plated) \| PPO + PA (Outer Covering) |
| Dimension | 17 x 17 x 2 cm |
| Quantity | 2 sets |
| Cost | &#8377;799 |

Table 17: Specification of T4 connector

[Product Link](https://www.amazon.in/Kenbrook-Solar-T4-Connector-Support/dp/B09BK14GVL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)

---

### 8.2. Mechanical Specifications
#### 8.2.1. Solar Panel Mounts

Panel mounts are used to fix solar panels on surfaces like roofs, building facades, or ground. The panel array is mounted with each panel aligned at an angle. This angle is variable and mounts should be bought according to the type of rooftop. We'll be using ones with 25° inclination.


<figcaption><b>Figure 14:</b> Solar Panel Mounts</figcaption>

We'll be using 1 such mount for our system, which consists of 4 panels.

| Specification (Single unit) | Value |
| --- | --- |
| Cost | &#8377;12,000 |
| Inclination | 25° |
| Dimensions(Leg) | 150cm X 60cm |
| Manufacturer | Loom Solar |
| Weight | 50kg |
| Material | Galvanised Iron |
| Holding Capacity | 4 Panels |

**Table 18:** Specification of solar panel mounts

[Product Link](https://www.loomsolar.com/collections/solar-panel-stand/products/loom-solar-2-row-design-4-panel-stand-375-watt)

---

## 9. Design

Here, we give a brief on how the off-grid energy solution is expected to look like after assembling the various components. We also give design blueprints and wiring diagrams wherever required, making necessary but plausible assumptions about the geography and architecture of the house.

<p align="center">
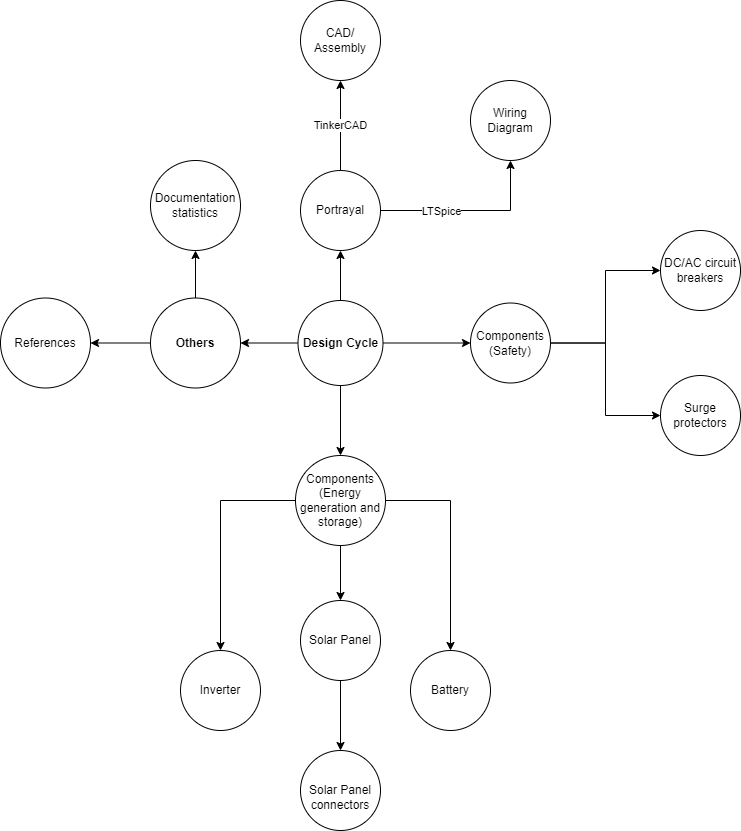
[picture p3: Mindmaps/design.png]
Mindmap for Design
	  
	 <figcaption align="center"><b>Figure 15:</b> Mindmap for Design</figcaption>
</p>

### 9.1. CAD/Assembly
The following image is the 3-D diagram of the designed house.
<p align="center" id = "front">
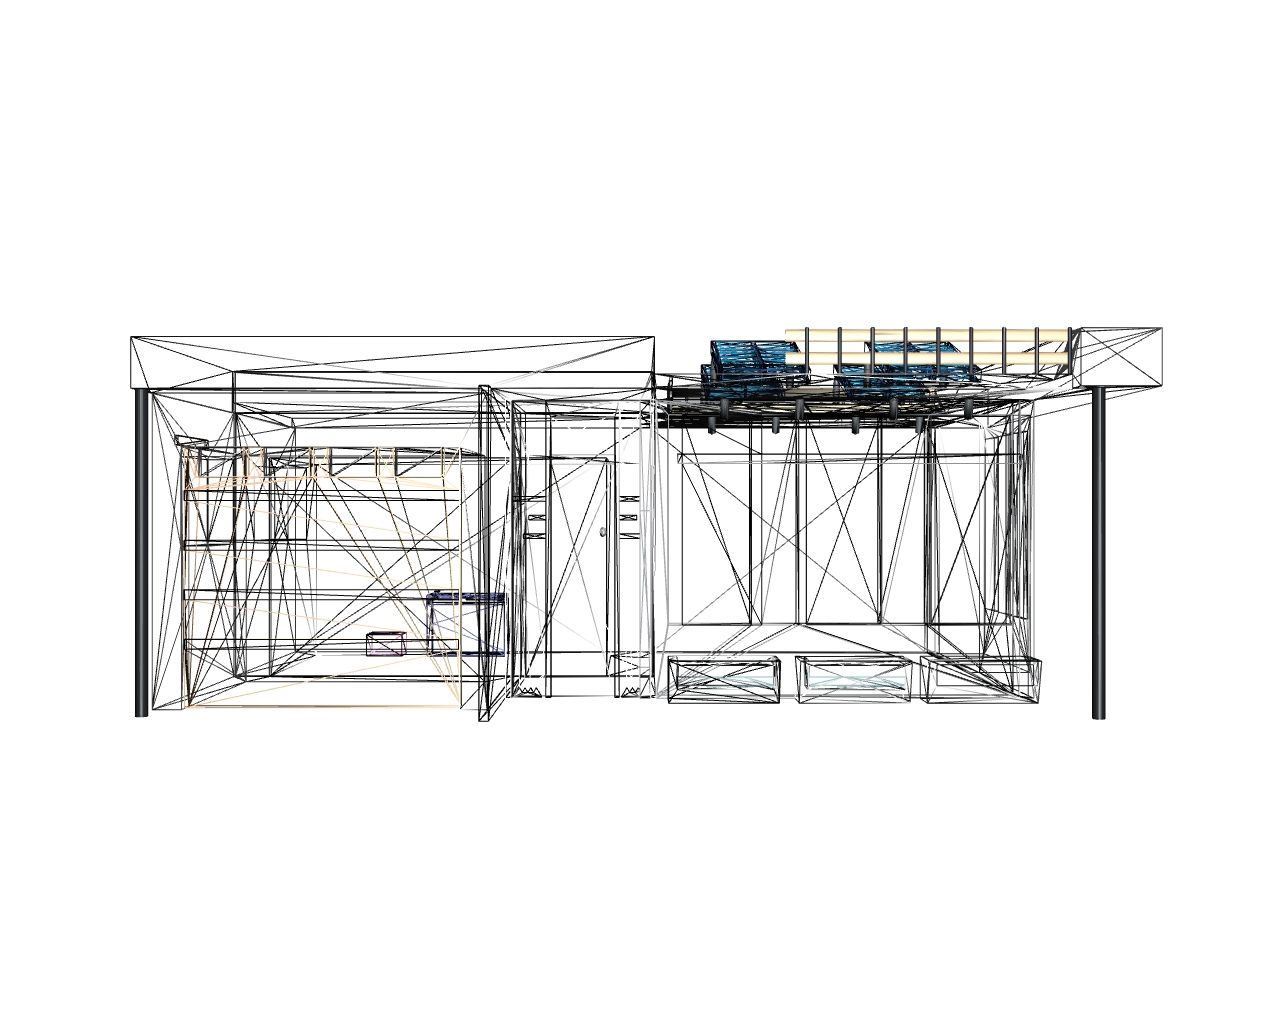
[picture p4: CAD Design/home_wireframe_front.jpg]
Front View
	
	<figcaption align="center"><b>Figure 16:</b> Front View of Designed House</figcaption>
</p>

<p align="center" id = "side">
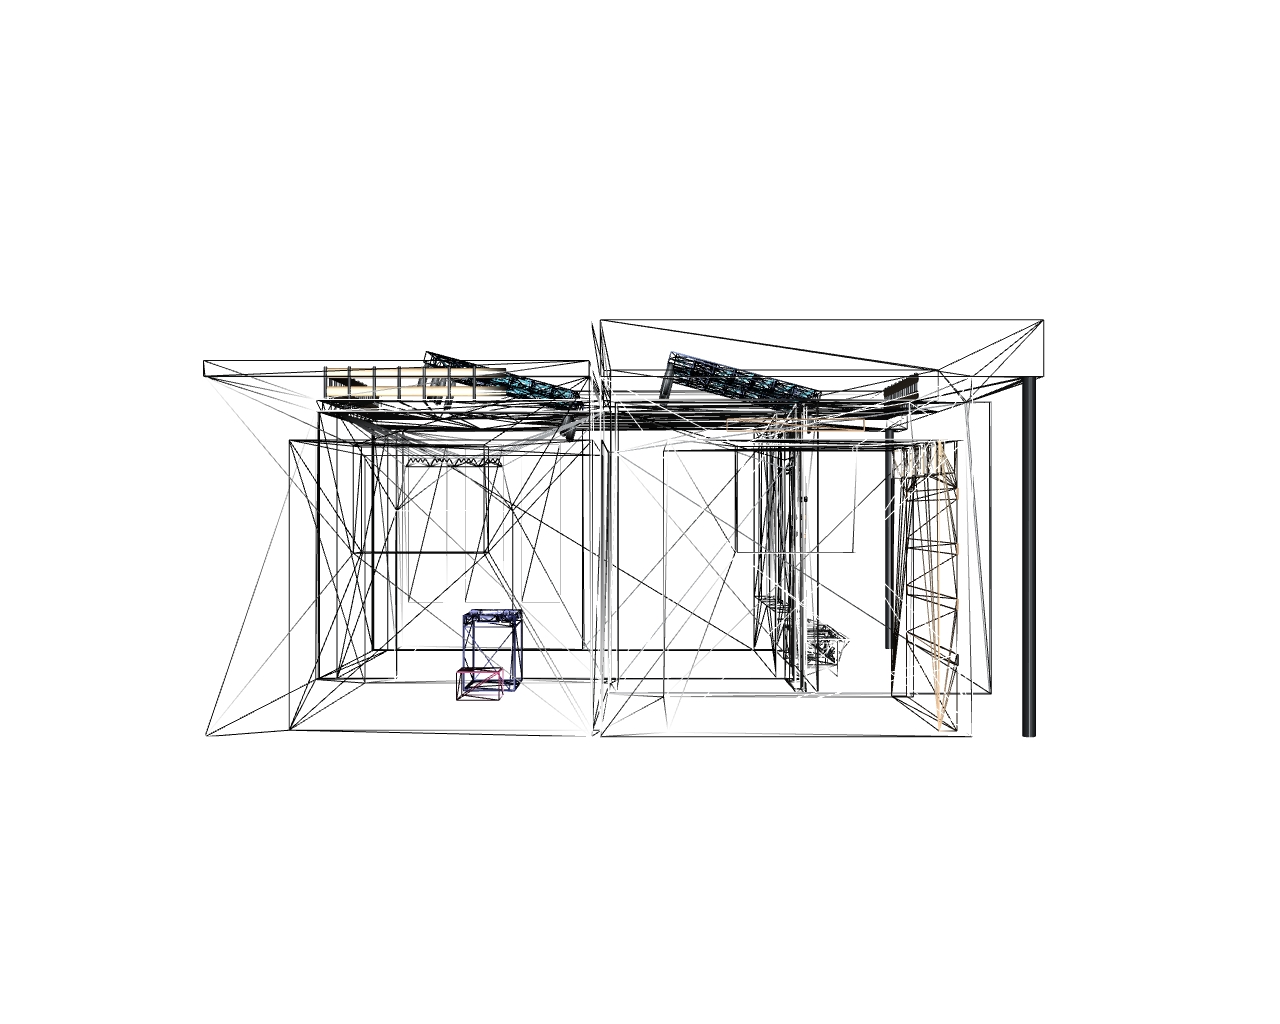
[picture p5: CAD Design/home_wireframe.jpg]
	 
	 <figcaption align="center"><b>Figure 17:</b> Side View of Designed House</figcaption>
</p>

<p align="center" id = "top">
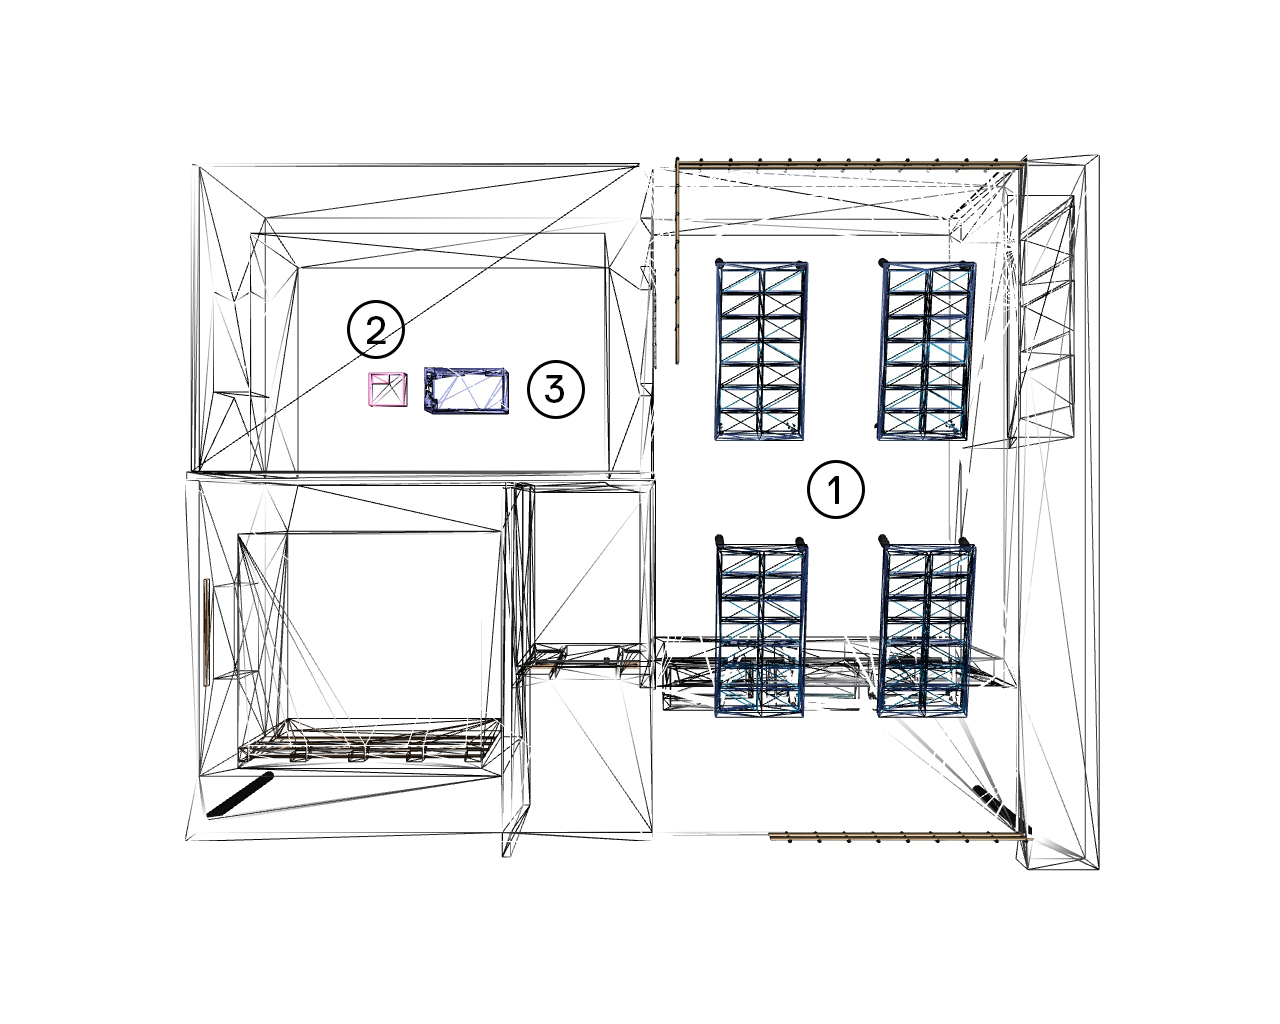
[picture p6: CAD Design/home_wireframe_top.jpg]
Top View
	 
	 <figcaption align="center"><b>Figure 18:</b> Top View of Designed House</figcaption>
</p>

<p align="center" id = "orthographic">
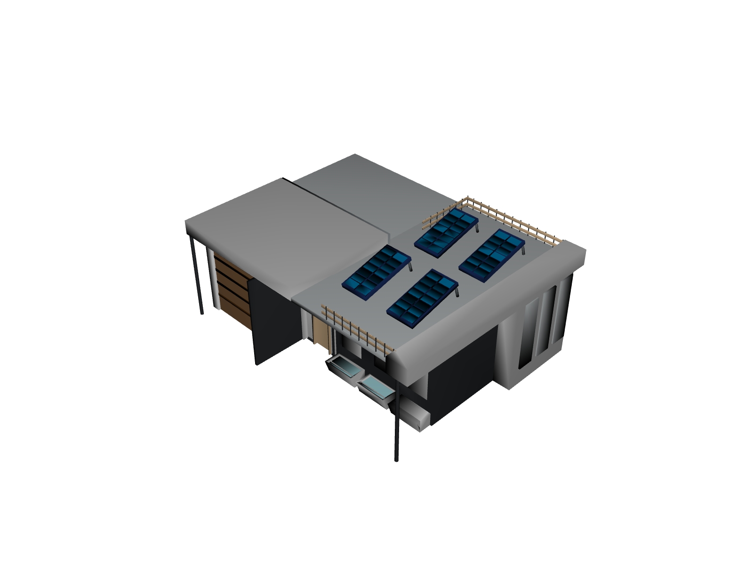
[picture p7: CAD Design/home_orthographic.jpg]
Isometric view
	  
	 <figcaption align="center"><b>Figure 19:</b> Orthographic View of Designed House</figcaption>
</p>

The components of our energy solution are detailed as follows:

***Label 1*** - Solar Panels
Solar panels to take the solar energy and give a DC current.

<p align="center" id = "panel_view">
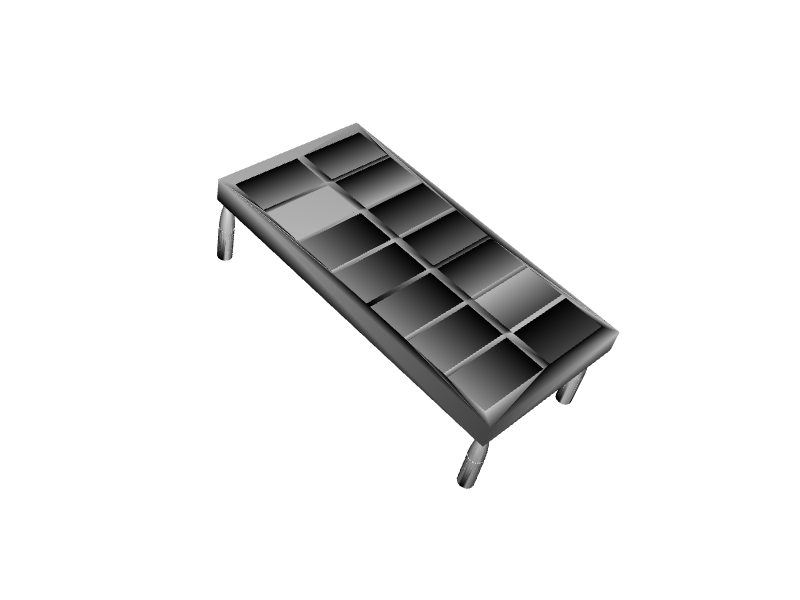
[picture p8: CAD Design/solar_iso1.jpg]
	 
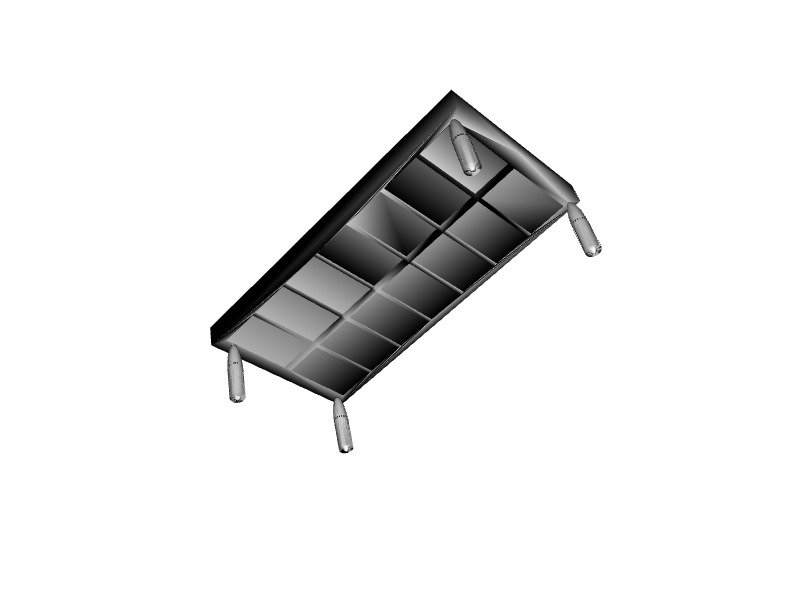
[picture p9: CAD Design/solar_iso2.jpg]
	
	<figcaption align="center"><b>Figure 20, 21:</b> Isometric Views of Solar Panel </figcaption>
</p>

***Label 2*** - Inverter  
Takes the solar DC current, and supply it power supply as well as store it in battery.

<p align="center" id = "inverter_view">
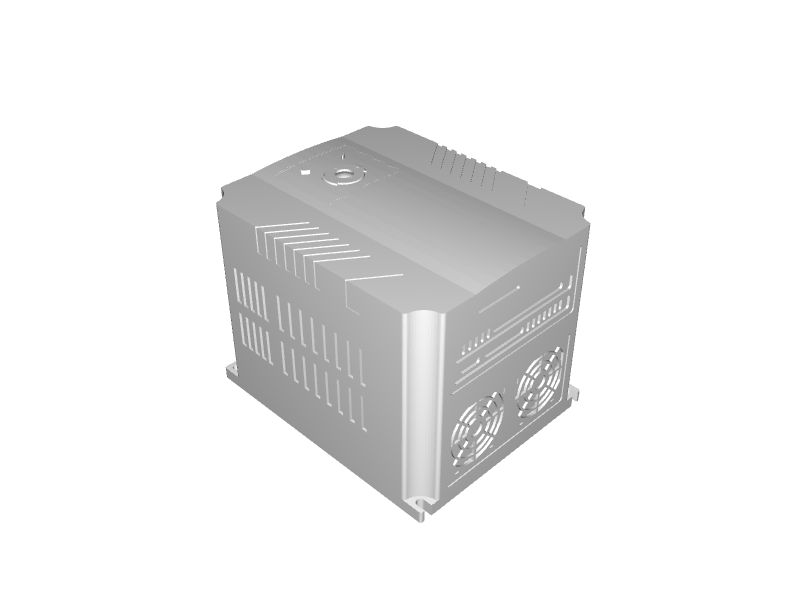
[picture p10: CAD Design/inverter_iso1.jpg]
	
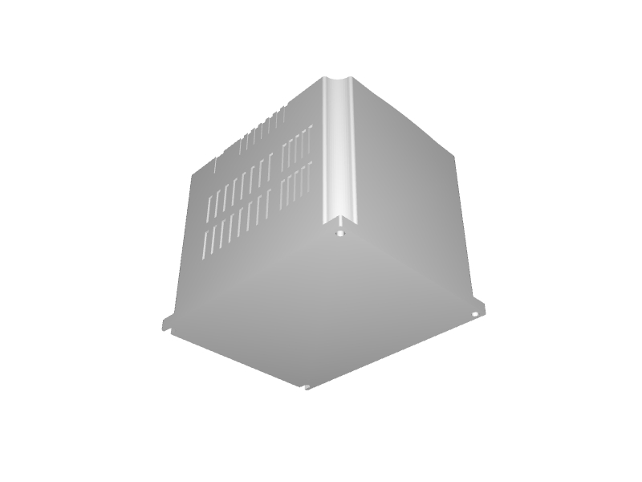
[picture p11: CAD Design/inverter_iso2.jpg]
	
	<figcaption align="center"><b>Figure 22, 23:</b> Isometric Views of Inverter</figcaption>
</p>

***Label 3*** - Battery  
Stores the solar converted electrical energy for further use when solar power cannot be harnessed e.g. Night. 

<p align="center" id="battery_view">
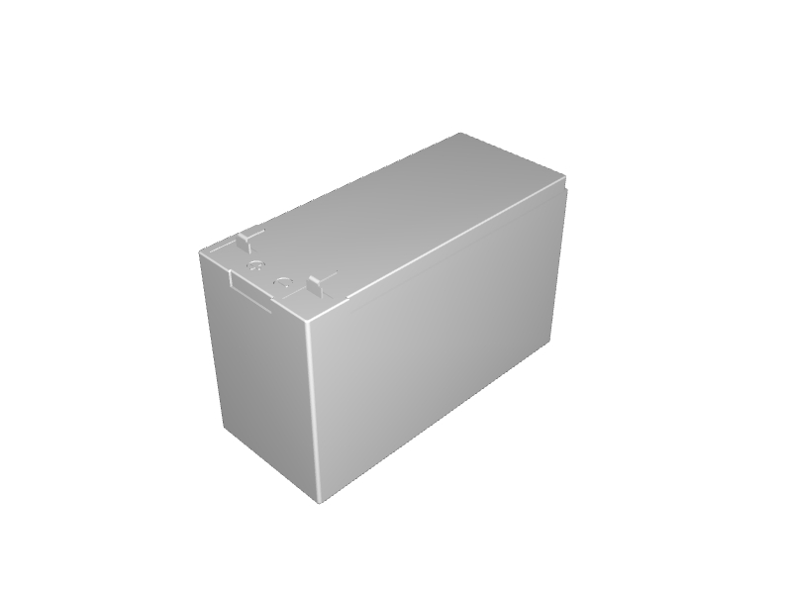
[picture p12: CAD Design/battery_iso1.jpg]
	
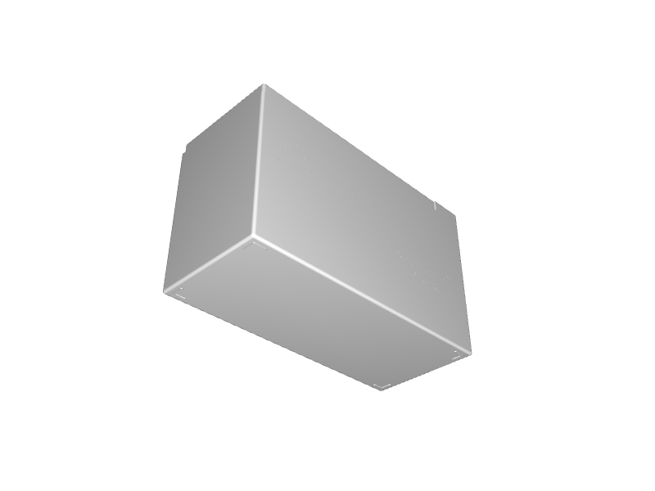
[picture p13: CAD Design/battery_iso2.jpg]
	
	<figcaption align="center"><b>Figure 24, 25:</b> Isometric Views of Battery</figcaption>
</p>

---

### 9.2. Wiring Diagram

The next step is to realize the design using all the components mentioned in the specifications by appropriately connecting them. The diagram below shows the connections for the same. 

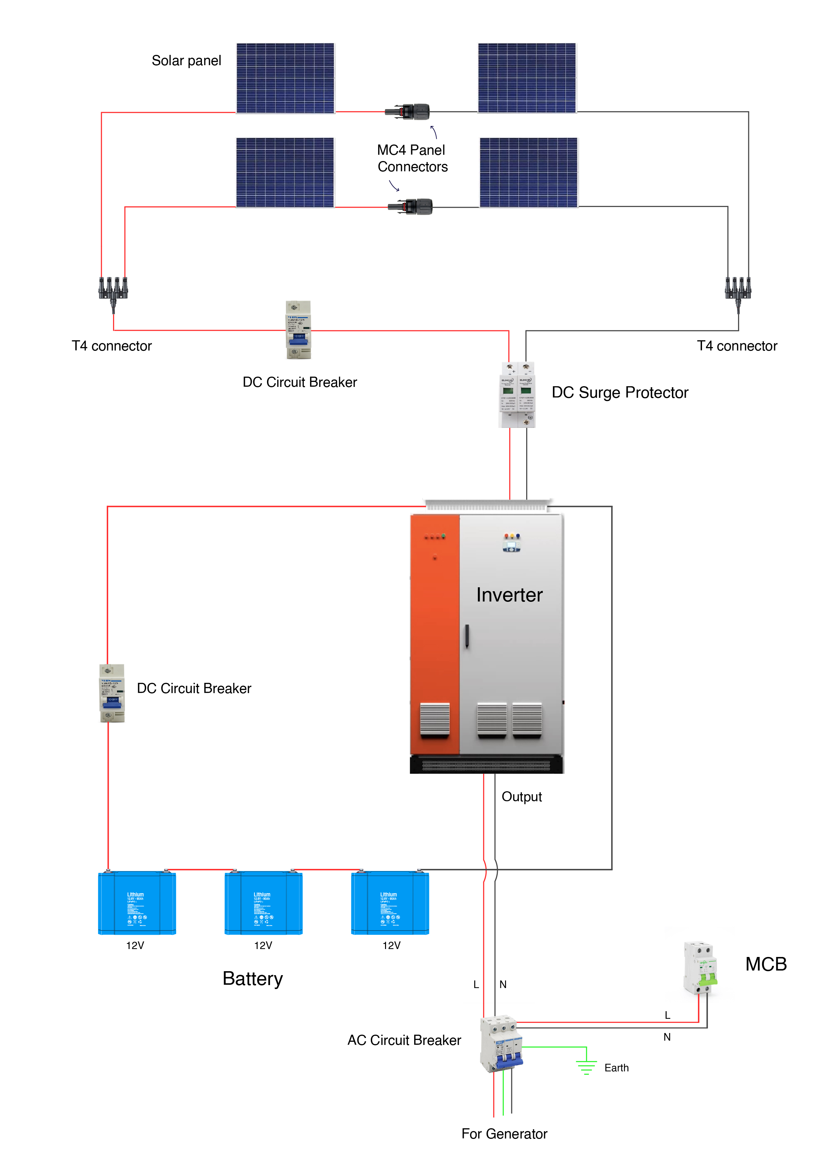
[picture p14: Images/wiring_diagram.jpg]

<figcaption align="center"><b>Figure 26:</b> Wiring Diagram</figcaption>

The solar panels are connected in a 2x2 fashion using the MC4 Panel Connectors. These are then connected to a DC Circuit Breaker using T4 connectors. The wires then go via a DC Surge Protector to the invertor which is connected to a series combination of 3 batteries of 12V each. The output of the invertor then goes to an AC circuit breaker which has also been connected to the generator for backup. This is finally connected to the MCB inside the house.

---

## 10. Cost Analysis

| Component | Price | Quantity | Total Price | Vendor |
| --- | --- | --- | --- | --- |
| Battery | &#8377;12,150 | 3 | &#8377;36,450 | [Product Link](https://www.amazon.in/LUMINOUS-RC-18000-Tubular-Battery/dp/B0713S16VF) |
| Backup Generator | &#8377;22,900 | 1 | &#8377;22,900 | [Product Link](https://www.indiamart.com/proddetail/1-kva-portable-petrol-generator-23901047630.html) |
| Hybrid Solar Invertor | &#8377;39,950 | 1 | &#8377;39,950 | [Product Link](https://www.urbanurja.com/products/luminous-solarverter-pro-pcu-3-kva-36v-mppt-solar-inverter) |
| Solar Panels | &#8377;20,000 | 4 | &#8377;80,000 | [Product Link](https://www.loomsolar.com/products/loom-solar-panel-shark-super-high-efficiency-module) |
| Solar DC Cable (15 m) | &#8377;1,990  | 2 | &#8377;3,980 | [Product Link](https://www.amazon.in/Microtek-Solar-Cable-Protected-15Meter/dp/B08BBYX28X/) |
| Household connection wire (90 m) | &#8377;2,949  | 1 | &#8377;2,949 | [Product Link](http://dl.flipkart.com/dl/havells-hrfr-pvc-2-5-sq-mm-black-90-m-wire/p/itmbcd2c1b016975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) |
| AC Circuit Breaker | &#8377;1,500  | 1 | &#8377;1,500 | [Product Link](https://www.amazon.in/Siemens-Pole-White-1-Piece-5SL64637RC/dp/B01D4QL6RC) |
| DC Circuit Breaker | &#8377;999 | 2 | &#8377;1,998 | [Product Link](https://www.amazon.in/FEEO-63A-Double-Pole-MCB/dp/B01LF8E0T2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) |
| DC Surge Protection Device | &#8377;799 | 1 | &#8377;799 | [Product Link](https://www.amazon.in/Kenbrook-Solar-Elmak-Protection-Device/dp/B09NTQDJGP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) |
| Porcelsian Fuse | &#8377;185 | 1 | &#8377;185 | [Product Link](https://www.amazon.in/Anchor-9311-Porcelain-Pilot-Ivory/dp/B00V4VJ7IK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) |
| MC4 Solar Panel Connectors | &#8377;449 | 2 | &#8377;898 | [Product Link](https://www.amazon.in/Kenbrook-Solar-Connector-Panel-Connection/dp/B08VNW7DLP/) |
| 4 in 1 T4 Connector | &#8377;799 | 2 | &#8377;1,598 | [Product Link](https://www.amazon.in/Kenbrook-Solar-T4-Connector-Support/dp/B09BK14GVL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) |
| Solar Panel Mount | &#8377;18,000 | 1 | &#8377;18,000 | [Product Link](https://www.loomsolar.com/collections/solar-panel-stand/products/loom-solar-2-row-design-4-panel-stand-375-watt) |
| Installation Cost | | | &#8377;12,320 | [Product Link](https://www.loomsolar.com/blogs/collections/solar-panel-installation-cost-in-india) |
| Electrician Charges | | | &#8377;3,000 | [Product Link](https://www.urbancompany.com/request/electricians) |
| Total Price | | | &#8377;2,11,527 |

**Table 19:** Cost Analysis

---

## 11. Reuse of Materials

- **Solar Panels** 

    - **Create Greenhouses:** A greenhouse is generally made up of glass and so are solar panels. We can easily make use of them and keep our plants warm throughout the cooler months. The junction box and frame are separately removed to recover copper and aluminum. Both of these materials are 100% reusable.
    
    - **Use Them as Insulation:** We can use our old solar panels to create walls and insulation to make our home even more eco-friendly.
    
- **Battery**

    - **Solar Powered Generator:** We can make a solar-powered generator using old or dead batteries and this could be sufficient for 25 hours if we use energy saving bulbs.
    
    - **A Portable Rechargeable Lighting System:** We can make portable rechargeable lighting systems using old or dead batteries. All we need is – LED plate, On/off switch, Diode IN4007, 1000 Ohms Resistor, Red LED light, Charging socket, Superglue, Soldering tool.

- **Mounting apparatus**

    - These are structures made of galvanized iron and can be used for mounting other solar panels or can also be sold as scrap iron to manufacture other equipment.

- **Backup Generator**

    - Generator is always needed for family reunions, weddings, cookouts and other outdoor parties to provide power.
    
    - Generators can be used to store the energy captured by solar panels to be used later instead of sending it back to the grid.

- **Disconnects**
    
    - Circuit breaker is reusable and can be reset after it has tripped due to overloads.

- **Inverter**
    
    - The DC electricity generated by the solar panels is converted into AC using this inverter, for powering all electrical appliances, lighting, power tools etc. in the house.

---

## 12. Project Management

### 12.1. Gantt Chart and CPM
<p align="center">
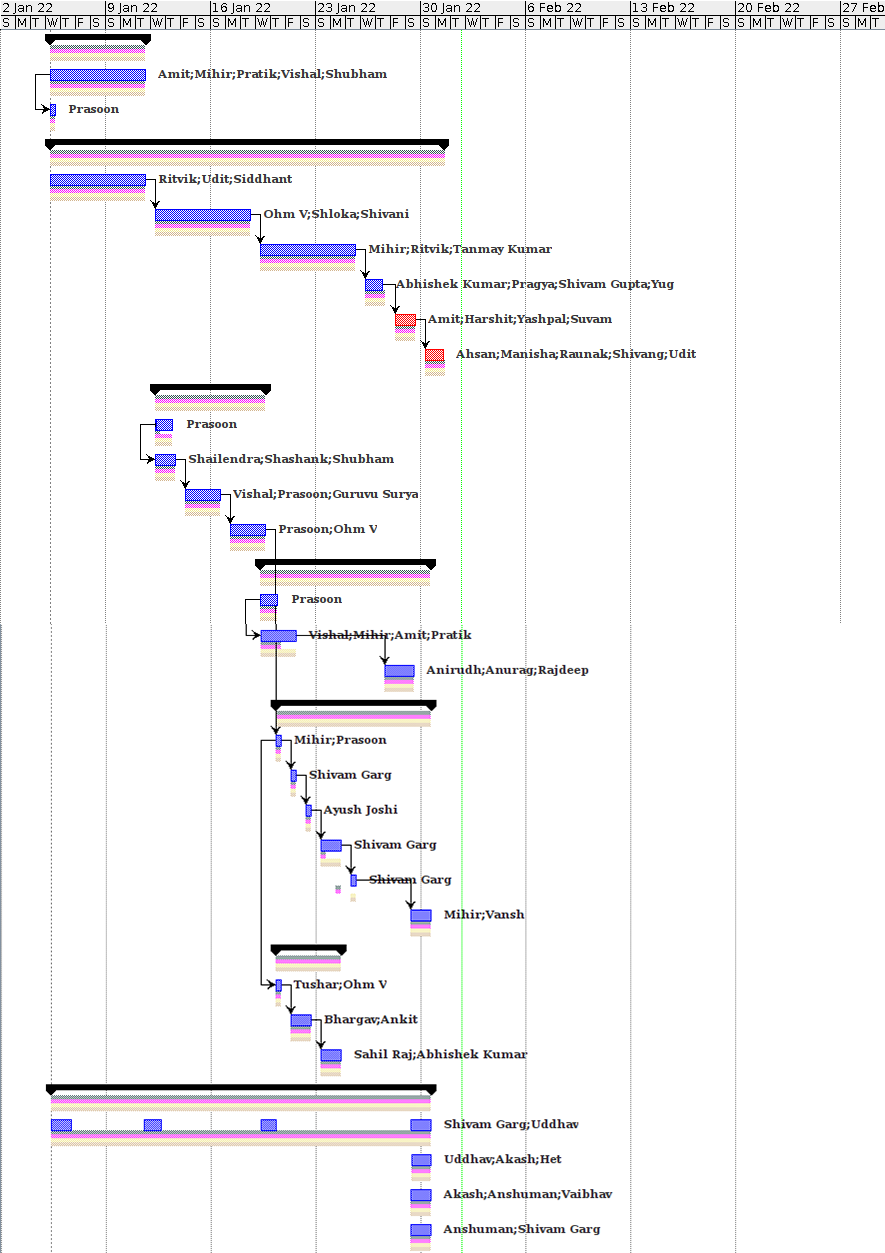
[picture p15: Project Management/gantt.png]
Gantt chart
	  
	 <figcaption align="center"><b>Figure 27:</b> Gantt Chart</figcaption>
</p>

The red path in Fig. 27 indicates the **critical path**. These critical paths are closely monitored and prioritized as any faults with their execution could have lead to delays in the sub-team pipelines. This in turn could have caused further unforeseen delays in the development of the final report.  

Fig. 28 shows the start dates and durations of various subteams in the project. It also details the name of the people who were involved in the coordination and functioning of the concerned sub-team.

<p align="center">
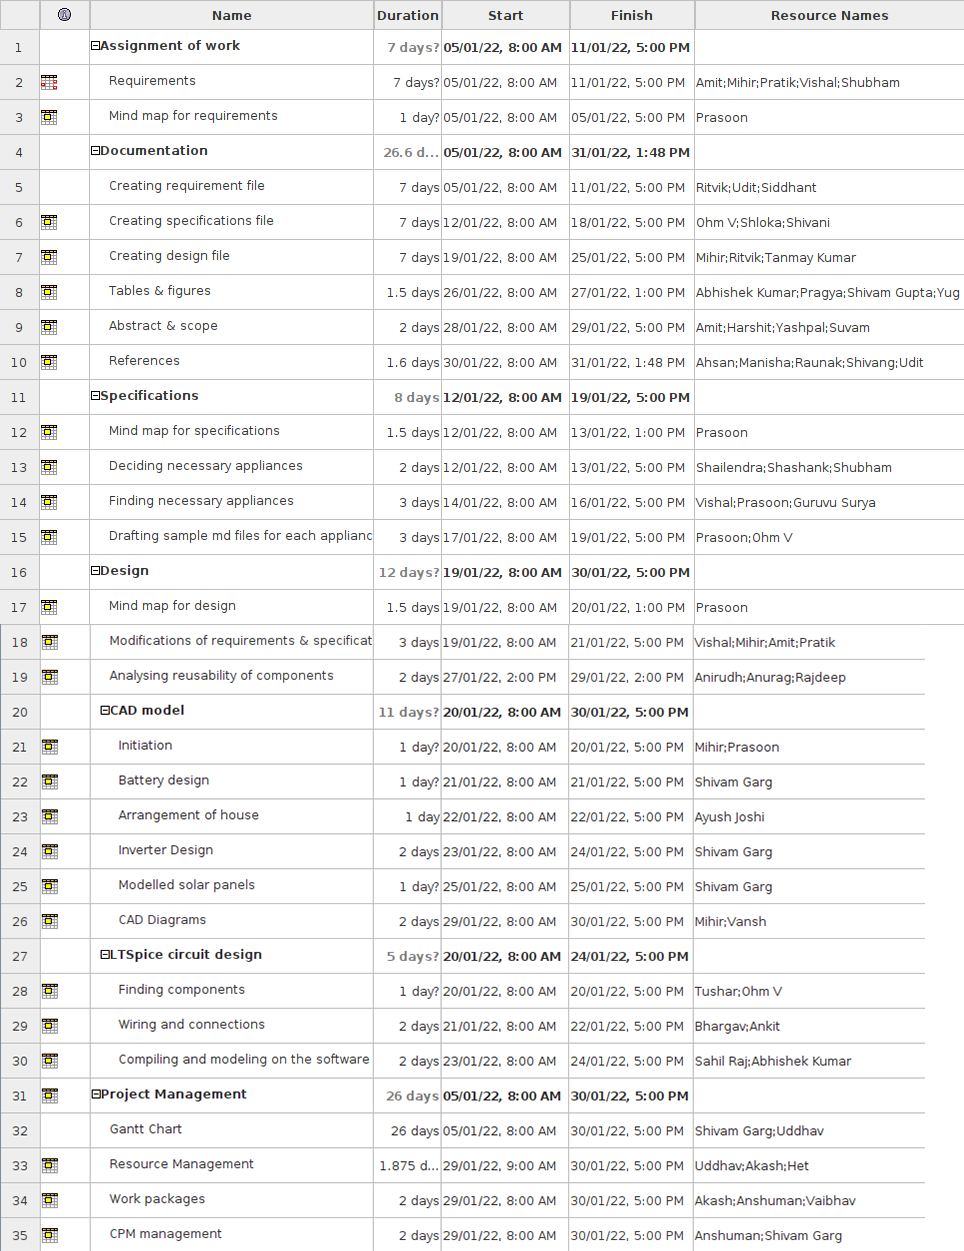
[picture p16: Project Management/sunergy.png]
Work breakdown structure
	  
	 <figcaption align="center"><b>Figure 28:</b> Work breakdown structure</figcaption>
</p>

### 12.2. Resources Chart

Fig. 29 shows the resources available (In this the tribe members), a gear symbol against a name indicates that the member was involved in the project actively and participated in the preparation of the final report in some capacity.
<p align="center">
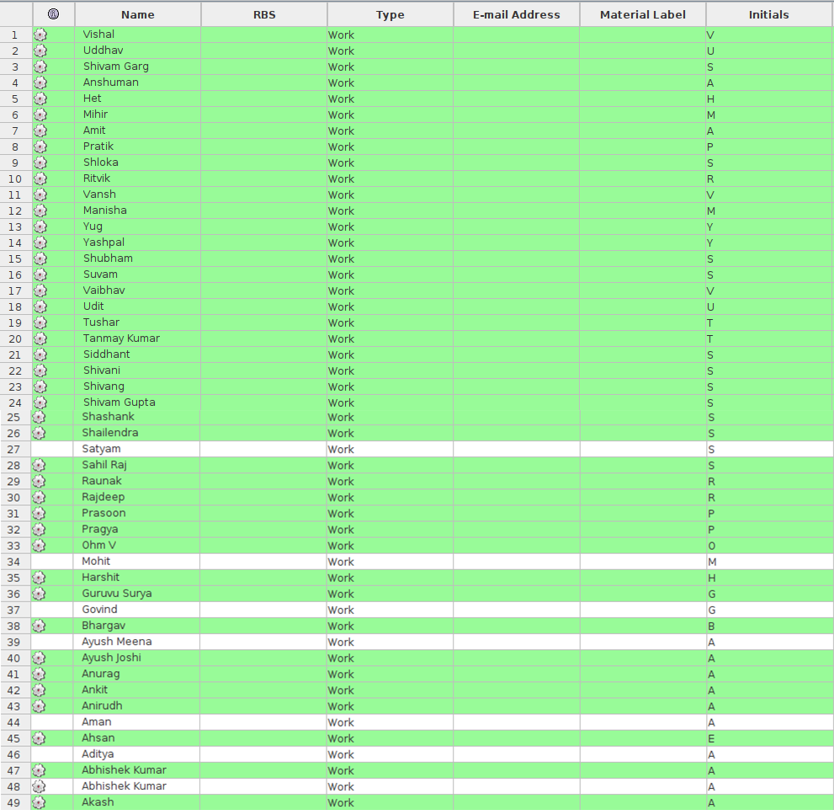
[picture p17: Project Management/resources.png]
Resource management
	  
	 <figcaption align="center"><b>Figure 29:</b> Resources</figcaption>
</p>

### 12.3. Work Packages 

Fig. 30 to Fig. 35 shows the work breakdown structure of the various sub-teams and how work was distributed among these teams. The work breakdown charts also provide a visual overview of any sub-sub-teams that were created to streamline the process even further.
<p align="center">
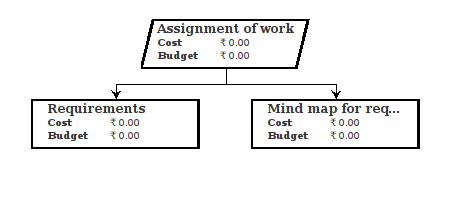
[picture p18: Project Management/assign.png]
	  
	 <figcaption align="center"><b>Figure 30:</b> Assignment of Work</figcaption>
</p>
<p align="center">
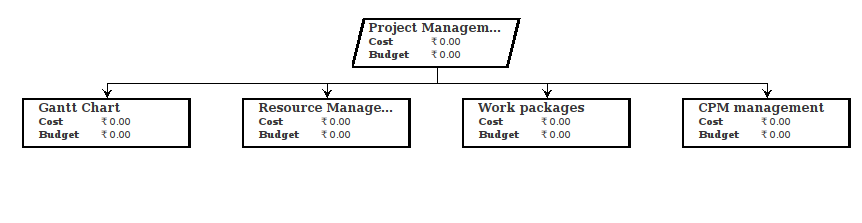
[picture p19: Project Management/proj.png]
	  
	 <figcaption align="center"><b>Figure 31:</b> Project Management</figcaption>
</p>
<p align="center">
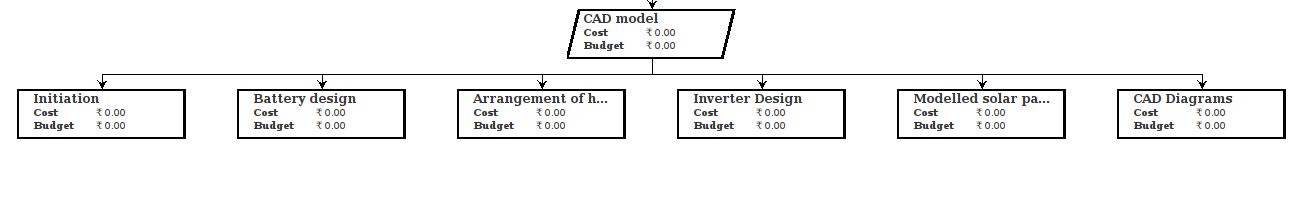
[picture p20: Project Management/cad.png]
	  
	 <figcaption align="center"><b>Figure 32:</b> CAD Model</figcaption>
</p>
<p align="center">
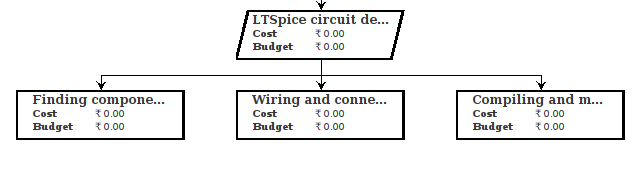
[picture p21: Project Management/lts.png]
	  
	 <figcaption align="center"><b>Figure 33:</b> Circuit design</figcaption>
</p>
<p align="center">
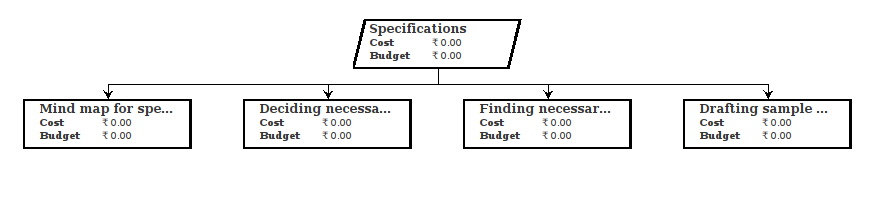
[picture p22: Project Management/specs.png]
	  
	 <figcaption align="center"><b>Figure 34:</b> Specifications</figcaption>
</p>
<p align="center">
	 Work Breakdown Structure 
	 <figcaption align="center"><b>Figure 35:</b> Documentation</figcaption>
</p>

---

## 13. Attributions

While designing this solution for off grid living, we used a number of softwares/extensions for various aspects of the project. These include -

- [**WordCounter**](https://wordcounter.net/): For obtaining the document text statistics
- [**Readability Check (VS Code Extension)**](https://marketplace.visualstudio.com/items?itemName=jemcclin.readabilitycheck): For obtaining readability indices scores for the document
- [**Markdown All in One (VS Code Extension)**](https://marketplace.visualstudio.com/items?itemName=yzhang.markdown-all-in-one): For Markdown utilities such as TOC generation, automatic formatting and auto-completion
- [**ProjectLibre**](https://www.projectlibre.com/): For project management tools
- [**Draw.io**](https://app.diagrams.net/): For creating mind maps
- [**Tinkercad**](https://www.tinkercad.com/): For designing 3D models and plans for the project
- [**GLC Player**](https://sourceforge.net/projects/glc-player/): For exporting the OBJ models from Tinkercad to images
- [**Excalidraw**](https://excalidraw.com/): For designing the circuit diagram for the project
- [**Zotero**](https://www.zotero.org/): For collecting and managing references

---

## 14. References

_Are Solar Panels Recyclable? (And 7 Ways to Reuse Them) - Conserve Energy Future_. (2020, December 28). https://www.conserve-energy-future.com/are-solar-panels-recyclable.php

_Don’t Dispose, Reuse: 5 DIY Projects Using Old or Dead Batteries_. (2021, June 22). MUO. https://www.makeuseof.com/dont-dispose-reuse-diy-projects-using-old-or-dead-batteries/

_Dsola-Factory-Customized-High-Efficient-T4-Solar-Connector.jpg (800×906)_. (n.d.). Retrieved February 1, 2022, from https://image.made-in-china.com/44f3j00sfSTKWnPEyrL/Dsola-Factory-Customized-High-Efficient-T4-Solar-Connector.jpg

Dubey, S., Sarvaiya, J. N., & Seshadri, B. (2013). Temperature Dependent Photovoltaic (PV) Efficiency and Its Effect on PV Production in the World – A Review. _Energy Procedia_, _33_, 311–321. https://doi.org/10.1016/j.egypro.2013.05.072

_E4 LCD Pro 1000 S | 3D CAD Model Library | GrabCAD_. (n.d.). Retrieved February 1, 2022, from https://grabcad.com/library/e4-lcd-pro-1000-s-1

_How to Connect a Portable Generator to the Home Supply—4 Methods_. (n.d.). Retrieved February 1, 2022, from https://www.electricaltechnology.org/2013/11/how-to-connect-portable-generator-to-home-supply.html

_HTB1CF0DHFXXXXaiXXXXq6xXFXXXB.jpg_.webp (984×479)_. (n.d.). Retrieved February 1, 2022, from https://sc01.alicdn.com/kf/HTB1CF0DHFXXXXaiXXXXq6xXFXXXB/201135244/HTB1CF0DHFXXXXaiXXXXq6xXFXXXB.jpg_.webp

_LiFePO4 Rechargeable Battery Pack | 3D CAD Model Library | GrabCAD_. (n.d.). Retrieved February 1, 2022, from https://grabcad.com/library/lifepo4-rechargeable-battery-pack-1

Luminous India. (2022, January 18). _Solarverter PRO PCU Installation_. https://www.youtube.com/watch?v=BmDQkVR5orU

_More Information on Circuit Breakers_. (n.d.). Retrieved February 1, 2022, from https://www.interpower.com/ic/designers/in-depth-product-line-information/More-information-on-Circuit-Breakers.html

mowgliadventures. (2020, July 23). 600w Solar Panel Kit for RV & Campervans Including Wiring Diagrams. _Mowgli Adventures_. https://mowgli-adventures.com/600-watt-solar-panel-wiring-diagram/

Palmetto. (n.d.). _Solar Generators: A Guide to Portable Solar Power_. Retrieved February 1, 2022, from https://palmetto.com/learning-center/blog/solar-generators-guide-portable-solar-power

Sizing MPPT Charge Controllers—DIY Renewable Energy Resources. (2020, September 17). _DIY Solar & Renewable Energy Resources_. https://www.altestore.com/diy-solar-resources/sizing-mppt-charge-controllers/

Solar Power. (n.d.). _Down to Earth Homesteaders_. Retrieved February 1, 2022, from https://downtoearthhomesteaders.com/resources/solar-power/

Sundaram, V. (2021, July 23). Battery Monitoring is Critical for EV Safety. _Power Electronics News_. https://www.powerelectronicsnews.com/battery-monitoring-is-critical-for-ev-safety/

_The 7 Components of Your Solar Power System_. (n.d.). Alternative Energy Tutorials. Retrieved February 1, 2022, from https://www.alternative-energy-tutorials.com/solar-power/7-components-of-your-solar-power-system.html

---

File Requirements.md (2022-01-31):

# ELP305 Design and Systems Laboratory
## Semester 2, 2021-2022 
### Tribe E

# 1. SUNERGY Requirements

In the following document, we give a brief on various traits that our off-grid living solution must possess. We also jot down the various requirements that will be needed to ensure our proposed solution is as efficient and trustworthy as possible.

---

##### Table of Contents:
- [1. **SUNERGY Requirements**](#1-sunergy-requirements)
  - [1.1 **Base Setup**](#11-base-setup)
  - [1.2 **Basic Requirements**](#12-basic-requirements)
  - [1.3 **Technical Requirements**](#13-technical-requirements)
  - [1.4 **Documentation Statistics**](#14-documentation-statistics)
  - [1.5 **Document Readability indices**](#15-document-readability-indices)
  - [1.6 **References**](#16-references)

| S.No.|Tables |
|:-:|:-: |
| 1 |[**Power Requirements**](#12-basic-requirements)|
| 2 | [**Documentation Statistics**](#14-documentation-statistics)|
| 3 | [**Document Readability indices**](#15-document-readability-indices) |

| S.No.|abbreviation | Stands For |
|:-:|:-:|:-:|
| 1 |**kWh**| kiloWatt hour |
| 2 |**kW**| kiloWatt|
| 3 |**W**| Watt|
|4  |**MCB**| Miniature Circuit Breaker|
|5| **AC**| Alternating Current|
|6| **DC**| Direct Current|

---

## 1.1 Base Setup

One of the main requirements for the system is that it is reasonably easy to set up so that minimum technical assistance is required for the same, and the house owner can perhaps even set it up himself.
These requirements require the system to be:

-   **Easy to implement**: The system should be easy to implement so that any person with little or no technical experience can implement and install the system by following simple instructions. The system also needs to be easy to repair so that there are minimum power cuts.
-   **Low maintenance**: The system needs to require low maintenance so that the user does not have to get it serviced frequently. If possible, it should be such that the users can themselves service it.
-   **Set-up time**: The system should be able to be set up within a short duration of time (3-4 days) to avoid any inconvenience in the form of power breaks to the users during the setup.
-   **Easy to Remove**: The system should be easy to remove so that the user can remove the setup if they want to relocate to a new location. For this, the system should also allow easy transportation over long distances so that the user can take it with themselves
-   **Long-term sustenance**: Should sustain itself for long periods of time even in the absence of production (no solar production during winters).
-   **Backup Generator**: Need in cases of emergency, high power usage situations, and 2nd option for achieving the above goal (long-term sustenance).

---

## 1.2 Basic Requirements

Some of the basic user requirements are:

1. **Accommodation**: The energy generated should be able to satisfy the needs of a family of six.

2. **Power Requirements**: The daily power requirement is approximately 24-25 kWh. The explanation for the same can be seen as follows:

<!-- # table1 -->
| S. No. | Appliance | Number of Appliances | Power Consumed by Each | Daily Time Consumption | Total Energy Consumed  | Explanation |
| --- | --- | --- | --- | --- | --- | --- |
| 1 | Tube Light | 8 | 0.02kW | 8 Hours | 0.02\*4\*8=0.64kWh | Assuming, on average, 4 lights out of 8 are ON for 8 hours. |
| 2 | LED Bulbs | 4 | 0.04kW | 6 Hours | 0.04\*3\*6=0.72kWh | Assuming, on average, 3 lights out of 4 are ON for 6 hours. |
| 3 | Ordinary ceiling fan | 6 | 0.075kW | 10 Hours | 0.075\*4\*10=3kWh |  Assuming, on average, 4 fans out of 6 are ON for 8 hours.  Only in Summers |
| 4 | Induction Stove | 1 | 1.8kW | 2 Hour | 1.8\*1\*2=3.6kWh | |
| 5 | Water Heater | 2 | 1.5kW | 1 Hour | 1.5\*2\*1=3kWh | Only in Winters |
| 6 | Laptop Adapater | 1 | 0.045W | 10 Hours | 0.045\*1\*10=0.45kWh | |
| 7 | Miscellaneous (e.g TV 50 inch 0.1kW, PC 0.2kW) | | | | 1kWh | Assuming extra consumption to be 1kWh per day. |
| Daily power requirement | Summers//Winters | | | | 9.41//9.41 kWh ± 10% |

3. **Budget**: The cost of manufacturing should not be more than Rs. 3,00,000.

4. **Backup**: In case of any system failure, there must be a fuel generator strong enough to provide backup for the basic energy requirements.

5. **Water Requirements**: The energy should sustain the operation of bore pumps to satisfy the water requirements of the house.

6. **Season**: There should be suitable alternatives to meet the energy requirements with changing seasons such as substitutes for solar panels during the winter season.

7. **Maintenance**: The system should require low maintenance in terms of system longevity. This should also be easy-to-handle by the residents themselves.

8. **Efficiency**: The batteries used to store energy should be efficient in order to ensure longer periods of usage. The appliances can also be used in an energy saver mode.

9. **Safety**: There must be fuses and master controller or circuit breakers (MCB) in order to ensure safety in case of fluctuations or malfunction.

10. **Monitoring**: The system should have a provision for monitoring the total energy consumed by all major appliances.

11. **Remote Access**: The system should be equipped with a remote accessing facility of solar panels as well as the appliances.

---

## 1.3 Technical Requirements

Various technical apparatus and tools required to acheive our goal are:

1. **Solar Panels**: An assembly of photo-voltaic cells mounted and connected to each other used to harness solar energy and convert it into electrical energy. The electricity produced by solar panels is DC in nature. Some factors characteristic of a good solar panel are low price, high efficiency, low-temperature coefficient.

2. **Batteries**: Deep cycle batteries are used in order to store energy produced by the solar panels during the day to use during the night. In order to have a long battery life, we wish to have a battery with a larger number of charge/recharge cycles.

3. **Inverter**: Solar panels generate DC electricity which needs to be converted to AC electricity needed by many common household appliances which are achieved by using an inverter. We wish to have an inverter that is cheap and provides high efficiency in converting DC to AC with minimal power losses.

4. **Mounting apparatus**: Solar panels are usually connected to each other and then subsequently mounted either on the roof or on the ground. The panels must be mounted so as to ensure cooling airflow and in a manner where maximum sunlight is available to the panels throughout the day.

5. **Charge Controllers**: Charge controllers are used to control the amount of current fed into the battery by the solar panels.This ensures the batteries are not overcharged during the day and don't leak current back to the panels during the night. There are two types of charge controller devices available - PWM and MPPT of which MPPT though more expensive is upto 30% more efficient than PWM charge controllers.

6. **Battery Monitor**: This meter would allow us to get an idea of how much power is being generated, how much amount we are saving by using solar panels and helps monitor which appliances use more power to manage energy utility.

7. **Backup Generator**: In case of off-grid systems backup power supply like a generator can serve as an alternate power supply in case of cloudy days, high demand or other unforeseen circumstances. The environmental impact of the generator could be reduced by using alternative fuels like biodiesel.

8. **Disconnects**: These are manual switches that enable us to cut off the power supply to and from the inverter in case of maintenance. This prevents current from flowing beyond the switch to some damaged component.

9. **Smart Lights**: Smart lights can be used to track Daytime and thus switching on/off lights at necessary places accordingly. This would allow us to smartly switch off electrical appliances not being used in order to save energy.

10. **Wires**: Insulated copper or aluminum wires needed to connect various electrical components

11. **Bio Gas plant**(optional): A biogas plant can be set up to harness energy out of the biodegradable waste that is produced in the household. This can later be used in the form of cooking gas or processed through a biogas generator for an alternative electricity source.

---
## 1.4 Documentation Statistics

| Word Count | # unique words | # repeated words | # sentences | # characters | # characters w/o spaces | # syllables |
|---|---|---|---|---|---|---|
| 1560 | 647 | 913 | 41 | 9382 | 7888 | 2466 |

| Avg # words per sentence | Avg # characters per sentence | Avg # characters per word | Avg # syllables per word |
|---|---|---|---|
| 39 | 229 | 5.10 | 1.57 |

The above results were obtained using https://wordcounter.net/.

---

## 1.5 Document Readability indices
| Readability Index | Score |
|---|---|
| Flesch Reading Ease score | 57 |
| Dale-Chall Readability score | 12 |
| Flesch-Kincaid Grade level | 9 |
| The Coleman-Liau Index | 11 |
| Automated Readability Index | 10 |
| SMOG Formula score | 13 |
| Spache Readability score | 6 |

The above scores were obtained using Visual Studio Code extension called Readability Check by jemcclin.

---

## 1.6 References

-   https://www.alternative-energy-tutorials.com/solar-power/7-components-of-your-solar-power-system.html

---

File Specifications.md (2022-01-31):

# ELP305 Design and Systems Laboratory
## Semester 2, 2021-2022 
### Tribe E

# 2. SUNERGY Specifications
_The GitHub repository that our tribe is using is linked [here](https://github.com/CrypticPoet/off-grid-energy-design)_ [1].

In the following document, we give a brief on various specifications of the components that we will be using in our off-grid living solution. We also mention their properties and why we have chosen them along with the best quotation available for each component.

**NOTE:** These specifications may change as the design work progresses further.

---

##### Table of Contents:
- [2. **SUNERGY Specifications**](#2-sunergy-specifications)
  - [2.1 **Electrical Specifications**](#21-electrical-specifications)
    - [2.1.1 Battery](#211-battery)
      - [Luminous Red Charge RC 18000 150 Ah battery](#luminous-red-charge-rc-18000-150-ah-battery)
    - [2.1.2 Backup Generator](#212-backup-generator)
    - [2.1.3 Hybrid Solar Inverter (Built in Solar Charge Controller)](#213-hybrid-solar-inverter-built-in-solar-charge-controller)
      - [3KVA/ 36 V off Grid Solar Inverter](#3kva-36-v-off-grid-solar-inverter)
      - [Solar Charge Controller](#solar-charge-controller)
        - [Sizing](#sizing)
    - [2.1.4 High Efficiency Solar Panels](#214-high-efficiency-solar-panels)
    - [2.1.5 Wires](#215-wires)
      - [Solar DC Cable](#solar-dc-cable)
      - [Household connection wires](#household-connection-wires)
    - [2.1.6 Safety Measures](#216-safety-measures)
      - [AC Circuit Breaker](#ac-circuit-breaker)
      - [DC Circuit Breaker](#dc-circuit-breaker)
      - [DC Surge Protection Device](#dc-surge-protection-device)
      - [Porcelain Fuse](#porcelain-fuse)
    - [2.1.7 MC4 Connectors](#217-mc4-connectors)
      - [MC4 Solar Panel Connectors](#mc4-solar-panel-connectors)
      - [4 in 1 T4 Connector](#4-in-1-t4-connector)
  - [2.2 **Mechanical Specifications**](#22-mechanical-specifications)
    - [2.2.1 Solar Panel Mounts](#221-solar-panel-mounts)
  - [2.3 **Documentation Statistics** [2]](#23-documentation-statistics-2)
  - [2.4 **Document Readability indices** [3]](#24-document-readability-indices-3)
  - [2.5 **References**](#25-references)

#### List of Abbreviations 
|  S.NO.  | Abbreviation|Stands For|
 | :---:|:-----:|:--------------------:|
 |1.| A | Ampere|
 |2.| AC | Alternating Current|
 |3.| Ah | Ampere Hour|
 |4.| BIS | Bureau of Indian Standards|
 |5.| cm| centimetre|
|6.| °C | Degree Celsius| 
|7.| DC| Direct Current|
|8.| ETP | Electrolytic Tough Pitch |
|9.| ft | Feet | 
|10.| g | Gram |
|11.| Hz| Hertz|
|12.| H | Height|
|13.| HRFR|Heat Resistant Flame Retardant|
|14.| IMP| Current at Maximum Power|
|15.| IP | Ingress Protection|
|16.| kW| Kilo Watt|
|17.| kg | Kilogram|
|18.| kVA| Kilo Volt Ampere|
|19.| kWh| Kilo Watt Hour|
|20.| L | Litre|
|21.| LED| Light Emitting Diode|
|22.| hr| Hour|
|23.| MPPT | Maximum Power Point Tracking|
|24.| m | metre|
|25.| mm| milimetre|
|26.| mA| mili Ampere|
|27.| m<sup>2</sup>| metre square|
|28.| mm<sup>2</sup>| milimetre square|
|29.| misc| Miscellaneous|
|30.| MCB| Miniature Circuit Breaker|
|31.| MC4 Connector|Multi-Contact 4 mm diameter contact pin Connector|
|32.| PERC| Passivated Emitter and Rear Contact|
|33.| PWM| Pulse Width Modulation|
|34.| PC | Personal Computer |
|35.| PA| Polyamide|
|36.| PPO| Polyphenylene Oxide |
|37.| UV | UltraViolet|
|38.| V| Volt|
|39.| VMP| Voltage at Maximum Power|
|40.| Voc| Voltage at Open Circuit|
|41.| W| Watt|
#### List of Tables
|  S.NO.  | Specification Tables|
 | :---:|:-----:|
 | 1. |  [**Battery**](#211-battery)|
 |2.| [**Backup Genertaor**](#212-backup-generator)|
 |3.|[**Off Grid Solar Inverter**](#3kva-36-v-off-grid-solar-inverter)|
|4.|[**Solar Charge Controller**](#sizing)|
|5.|[**High Efficiency Solar Panels**](#214-high-efficiency-solar-panels)|
|6.|[**Solar DC Cables**](#solar-dc-cable)|
|7.|[**Household Connection Wires**](#household-connection-wires)|
|8.|[**AC Circuit Breaker**](#ac-circuit-breaker)|
|9.|[**DC Circuit Breaker**](#dc-circuit-breaker)|
|10.|[**DC Surge Protection Device**](#dc-surge-protection-device)|
|11.|[**Porcelain Fuse**](#porcelain-fuse)|
|12.|[**MC4 Solar Panel Connectors**](#mc4-solar-panel-connectors)|
|13.|[**4 in 1 T4 Connector**](#4-in-1-t4-connector)|
|14.|[**Solar Panel Mounts**](#221-solar-panel-mounts)|
|15.|[**Documentation Statistics**](#23-documentation-statistics-2)|
|16.|[**Document Readability Indices**](#24-document-readability-indices-3)|

 #### List of Figures
 |  S.NO.  | Figures|
 | :---:|:-----:|
 |1.|[**Luminous Red Charge RC 18000 150 Ah battery**](#luminous-red-charge-rc-18000-150-ah-battery)|
|2.|[**Off Grid Solar Inverter**](#3kva-36-v-off-grid-solar-inverter)|
|3.|[**Solar Panels**](#214-high-efficiency-solar-panels)|
|4.|[**Solar DC Cables**](#solar-dc-cable)|
|5.|[**Household Connection Wires**](#household-connection-wires)|
|6.|[**AC Circuit Breaker**](#ac-circuit-breaker)|
|7.|[**DC Circuit Breaker**](#dc-circuit-breaker)|
|8.|[**DC Surge Protection Device**](#dc-surge-protection-device)|
|9.|[**Porcelain Fuse**](#porcelain-fuse)|
|10.|[**MC4 Solar Panel Connectors**](#mc4-solar-panel-connectors)|
|11.|[**4 in 1 T4 Connector**](#4-in-1-t4-connector)|
|12.|[**Solar Panel Mounts**](#221-solar-panel-mounts)|
 
---

## 2.1 Electrical Specifications
### 2.1.1 Battery
#### Luminous Red Charge RC 18000 150 Ah battery

battery

- For heavy-duty application with excellent overcharge tolerance, superior performance during long frequent power cuts, and minimum maintenance
-  fast battery charging with adaptive battery charging control technology

| Specifications | Value |
|---|---|
| Brand | Luminous |
| Nominal Voltage | 12V |
| Rated Capacity(at room temp.) | 150 ah (at room temp.) |
| Protections | Dust & water proof with heavy plastic body |
| Charging Current(Boost mode) | 15.10A(starting), 7.60A(finishing) |
| Charging Current (Trickle mode) | 504 mA(max), 126 mA(min) |
| Weight | 53.30 Kg (28.5 Kg dry weight) (+/- 5%) |
| Dimensions | 50.2 $\times$ 44 $\times$ 19.1 cm (L $\times$ W $\times$ H) |
| Electrolyte Volume | 20L (+/-5%) |
| Water Level Indicators | 6 |
| Cost |  &#8377;12150 X 3 = &#8377;36450 |

---

### 2.1.2 Backup Generator

The generator size should be of 1kW. In our system, generator will mostly be needed during winter when there is a lack of solar energy production. Since this is a backup system the below power consumed is assumed to be calculated under minimal load when running backup generator.

Total Instantaneous Power Consumed = 0.020*2(light)+0.5(misc) = 0.58kW

**Note**: Here the misc includes PC,stove and other appliances that we might/might not use under emergency situation. The generator should be able to run under the above conditions for 9hr(which is minimum requirement for overnight functionality). Spare fuel should always be kept in case of emergencies. 

| Specification | Value |
| --- | --- |
| Manufacturer | Generic |
| Fuel | Petrol |
| Consumption | 1L/hr under full load |
| Capacity | 10L |
| Rated voltage | 220V+-15 |
| Peak output power  | 1kVA |
| Weight | 30kg |
| Cost | Rs. 22,900 |
| Size | 1kW |

[Product Link](https://www.indiamart.com/proddetail/1-kva-portable-petrol-generator-23901047630.html)

---

### 2.1.3 Hybrid Solar Inverter (Built in Solar Charge Controller)
### 3KVA/ 36 V Off Grid Solar Inverter

battery

Luminous Solar Hybrid Inverter 3kVA/36 is an off grid hybrid solar inverter which allows smart management of Solar Power, Grid Supply and Battery to deliever uninterrupted power for all electrical appliances. It comes built in with an mppt technology based Solar Charge Controller that converts solar energy into electricity and stores power. 
-   3 kva system with 3500 watt solar panel support
-   super efficient as low conversion loss from battery
-   LCD Battery Monitoring system with display parameters such as Input Power, Output power load, battery health, battery percentage, Overload, MCB Trip and Over Temperature Protection
-   Surge warnings, safety alarms and troubleshooting Fault Codes 
-   BIS certified solar inverter and IP-21 protection level.
-  MCB protection in the case of any short circuit
-  Comprehensive protection against short-circuit, reverse polarity, battery overload etc.

| Specification | Value |
| --- | --- |
| Brand | Luminous |
| Rated Power | 3kVA |
| Waveform | Pure sine wave |
| Output Voltage Regulation | 230VAC $\pm$ 2% |
| Output Frequency | 50 Hz |
| Battery Bank Voltage | 36 V(3x12V batteries) |
| Input Voltage Mains Mode | 180-260 VAC |
| Output Voltage Distortion(THD)| <=3% |
|Nominal Output Current from UPS| 11 A |
| Operating Temperature | 0 - 45<sup>.</sup>C |
| Input Protection | 32A MCB |
| Battery Charging Current | 14A, 17A, 21A |
| Max. Relative Humidity @25<sup>.</sup>C  | upto 95% |
| Dimensions | D x W x H (mm) 300 x 417 x 452 |
| Net Weight | 32.5 kg |
| Cost | Rs. 39,950 |

### Solar Charge Controller

Charge controllers are used to control the amount of current fed into the battery by the solar panels. This ensures the batteries are not overcharged during the day and don't leak current back to the panels during the night. So, Solar Charge Controller must be compatible with solar panel and the battery bank. Our Hybrid inverter comes built in with an MPPT Charge controller which is more efficient at DC Conversion compared to older PWM technology.

#### Sizing
Sizing of a controller depends on three factors
- Solar panel array’s maximum open-circuit voltage (Voc)
- Total Power rating of Solar panel array
- Battery Bank Voltage

Specifications of the in-built charge controller

| Specification | Value |
| --- | --- |
| Brand | Luminous |
| Type | MPPT |
| Nominal Battery Charging Current | 91A$\pm$ 2A |
| Maximum Battery Charging Current | <=100A$\pm$ 10A |
| Maximum PV Array Power | 3.5 kW |
| Maximum PV Input Current(Imp) | 38A |
| Solar Input Voltage VMP | 60V - 120V  |
| Solar Input Voltage VOC | 75V - 150V  |

[Product Link](https://www.urbanurja.com/products/luminous-solarverter-pro-pcu-3-kva-36v-mppt-solar-inverter#)

---

### 2.1.4 High Efficiency Solar Panels

Solar panels collect clean renewable energy in the form of sunlight and convert that light into electricity which can then be used to provide power for electrical loads. 

The panels which we're using, are based on [mono PERC cells](https://regenpower.com/news/why-choose-mono-perc-panels-rooftop-solar/), which results into higher electricity generation due to higher light absorption per unit area, when compared to traditional panels.
 
It also paves the way for more power output per panel, which means less number of panels are required for a given power requirement. It means less expenditure for 
[panel mounts](https://encrypted-tbn0.gstatic.com/images?q=tbn:ANd9GcSWhB7u8DxJiUJTM2uH5U-6Ml3h3SoByqJd8g&usqp=CAU).



We'll be using 4 such panels in our system.

| Specification (Single panel) | Value |
| --- | --- |
| Cost | &#8377;20,000 |
| Operating Voltage | 24V |
| Dimensions | 6.9ft X 3.4ft |
| Manufacturer | Loom Solar |
| Rated Output Power (Peak) | 440W |
| Output Voltage at max. power | 42V |
| Output Current at max. power | 10.5A |

*Above electrical data is for, Irradiance: 1000W/m² and Cell Temperature:25°C*

[Product Link](https://www.loomsolar.com/products/loom-solar-panel-shark-super-high-efficiency-module)

---

### 2.1.5 Wires
#### Solar DC Cable
DC Solar Panel cables are required to connect the array of solar panels in series with each other and then carry the output DC Current to the Solar Charge Controller.

When choosing DC Solar Panel wires, some things should be kept in mind
- The wires should be of sufficient diameter to ensure that no overheating occurs
- The wires should be of adequate current rating
- UV resistance to ensure longevity



| Specification | Value |
| --- | --- |
| Brand | Microtek |
| Current carrying capacity | 80 A |
| Cross Sectional Area | 10 mm² |
| Length | 15m Red and 15m Black |
| Cost | &#8377;1990 |

[Product Link](https://www.amazon.in/Microtek-Solar-Cable-Protected-15Meter/dp/B08BBYX28X/)

####  Household connection wires
Connecting wires would be used to connect different appliances in the energy grid.  Hence they should be able to carry high current and be well insulated.

connecting wires

| Specification | Value |
| --- | --- |
| Brand | Havells |
| Length | 90 m |
| Cross-sectional area | 2.5 sq mm |
| Current carrying capacity | 28 A |
| Voltage Grade | 1100 V |
| Insulation material | HRFR PV |
| Conductor material | ETP Grade Annealed Copper |
| Cost | &#8377;2,871 |

[Product Link](http://dl.flipkart.com/dl/havells-hrfr-pvc-2-5-sq-mm-black-90-m-wire/p/itmbcd2c1b016975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)

---
### 2.1.6 Safety Measures

 ####  AC Circuit Breaker
 
 A separate AC Breaker between the AC Input and Inverter is required to ensure tha the inverter can be securely disconnected during maintenance and secured from AC Input over current

 

| Specification  | Value |
| --- | --- |
| Brand | Siemens |
| Current Rating | 63 A |
| No. of Poles | 4 |
| Dimensions | 7.1 cm X 7 cm X 9 cm |
| Weight | 660 g |
| Material | Polycarbonate |
| Color | White |
| Cost | &#8377; 1500 |
 
 [Product Link](https://www.amazon.in/Siemens-Pole-White-1-Piece-5SL64637RC/dp/B01D4QL6RC)

#### DC Circuit Breaker

A DC Circuit breaker between the Solar Panels and Inverter is required for disconnecting the solar panels safely for maintenance or replacement. The Circuit breaker also protects the inverter from over current damage



| Specification | Value |
| --- | --- |
| Brand | FEEO |
| Circuit Breaker Type | Standard |
| Current Rating | 63 A |
| No. of Poles | 2 |
| Voltage | 800 V (DC) |
| Dimensions | 7.1 cm X 3.6 cm X 8 cm |
| Cost | &#8377;999 |

[Product Link](https://www.amazon.in/FEEO-63A-Double-Pole-MCB/dp/B01LF8E0T2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)

#### DC Surge Protection Device

The DC Surge Protector protects the inverter and panels from any unforeseen voltage surges in instances such as Lightning strikes



| Specification | Value |
| --- | --- |
| Brand | Kenbrook Solar |
| Overvoltage Rating | 600V |
| No. of Poles | 2 |
| Dimension | 9 cm X 6 cm X 3.5 cm |
| Weight | 245 g |
| Cost | &#8377;799 |

[Product Link](https://www.amazon.in/Kenbrook-Solar-Elmak-Protection-Device/dp/B09NTQDJGP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)

####   Porcelain Fuse


| Specification | Value |
| --- | --- |
| Brand | Anchor |
| AC Adapter Current | 32 A |
| Voltage | 415 V |
| Material | Ceramic |
| Dimensions | 10 cm X 5 cm X 5 cm |
| Cost | &#8377;185 |

[Product Link](https://www.amazon.in/Anchor-9311-Porcelain-Pilot-Ivory/dp/B00V4VJ7IK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)

---

### 2.1.7 MC4 Connectors
#### MC4 Solar Panel Connectors

MC4 Connectors are required for a safe and convenient connection between the solar panel arrays.   
The Kenbrook Solar MC4 Connectors are UV resistant, waterproof and anti-flame boasting an estimated life of upto 25 years and thus require minimum maintenance.



| Specification | Value |
| --- | --- |
| Brand | Kenbrook |
| Material | Copper (Tin Plated) \| PPO + PA (Outer Covering) |
| Dimensions | 6 x 4 x 2 cm |
| Quantity | 10 Male + Female MC4 Connectors |
| Cost | &#8377;449 |

[Product Link](https://www.amazon.in/Kenbrook-Solar-Connector-Panel-Connection/dp/B08VNW7DLP/)

#### 4 in 1 T4 Connector

T4 Connector is required to connect the 2x4 parallel solar panel array to the solar charge controller. The T4 connector also comes with UV Resistance, anti flame and water resistance



| Specification | Value |
| --- | --- |
| Brand | Kenbrook |
| Material | Copper (Tin Plated) \| PPO + PA (Outer Covering) |
| Dimension | 17 x 17 x 2 cm |
| Quantity | 2 sets |
| Cost | &#8377;799 |

[Product Link](https://www.amazon.in/Kenbrook-Solar-T4-Connector-Support/dp/B09BK14GVL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)

---

## 2.2 Mechanical Specifications
### 2.2.1 Solar Panel Mounts

Panel mounts are used to fix solar panels on surfaces like roofs, building facades, or ground. The panel array is mounted with each panel aligned at an angle. This angle is variable and mounts should be bought according to the type of rooftop. We'll be using ones with 25° inclination.



We'll be using 1 such mount for our system, which consists of 4 panels.

| Specification  (Single unit) | Value |
| --- | --- |
| Cost | &#8377;12,000 |
| Inclination | 25° |
| Dimensions(Leg) | 150cm X 60cm |
| Manufacturer | Loom Solar |
| Weight | 50kg |
| Material | Galvanised Iron |
| Holding Capacity | 4 Panels |

[Product Link](https://www.loomsolar.com/collections/solar-panel-stand/products/loom-solar-2-row-design-4-panel-stand-375-watt)

---

## 2.3 Documentation Statistics [2]

| Word Count | # unique words | # repeated words | # sentences | # characters | # characters w/o spaces | # syllables |
|---|---|---|---|---|---|---|
| 2637 | 922 | 1715 | 49 | 22879 | 16198 | 4471 |

| Avg # words per sentence | Avg # characters per sentence | Avg # characters per word | Avg # syllables per word |
|---|---|---|---|
| 54 | 467 | 6.1 | 1.69 |

The above results were obtained using https://wordcounter.net/.

---

## 2.4 Document Readability indices [3]

| Readability Index | Score |
|---|---|
| Flesch Reading Ease score | 58 |
| Dale-Chall Readability score | 8.3 |
| Flesch-Kincaid Grade level | 8 |
| The Coleman-Liau Index | 16 |
| Automated Readability Index | 12 |
| SMOG Formula score | 12 |
| Spache Readability score | 4 |

The above scores were obtained using Visual Studio Code extension called Readability Check by jemcclin.

---

## 2.5 References

[1] [GitHub - Off Grid Energy Design - Tribe E](https://github.com/CrypticPoet/off-grid-energy-design)

[2] [WordCounter - Count Words & Correct Writing](https://wordcounter.net/)

[3] [Readability Check - Visual Studio Marketplace](https://marketplace.visualstudio.com/items?itemName=jemcclin.readabilitycheck)

---

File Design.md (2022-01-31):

# ELP305 Design and Systems Laboratory
## Semester 2, 2021-2022 
### Tribe E

# 3. SUNERGY Design
_The GitHub repository that our tribe is using is linked [here](https://github.com/CrypticPoet/off-grid-energy-design)_ [1].

In the following document, we give a brief on how the off-grid energy solution is expected to look like after assembling the various components. We also give design blueprints and wiring diagrams wherever required, making necessary but plausible assumptions about the geography and architecture of the house.

**NOTE:** Some specifications have been changed after taking the design into consideration. These updated requirements/specifications are available in the GitHub repository.

---

##### Table of Contents:
- [3. **SUNERGY Design**](#3-sunergy-design)
  - [3.1 **CAD/Assembly**](#31-cadassembly)
  - [3.2 **Wiring Diagram**](#32-wiring-diagram)
  - [3.3 **Documentation Statistics**](#33-documentation-statistics)
  - [3.4 **Document Readability indices**](#34-document-readability-indices)
  - [3.5 **References**](#35-references)

| S.No.|Tables |
|:-:|:-: |
| 1 | [**Documentation Statistics**](#33-documentation-statistics)|
| 2 | [**Document Readability indices**](#34-document-readability-indices) |

| S.No.| Figures |
|:-:|:-: |
| 1 |[**Front View of Designed House**](#front)|
| 2 | [**Side View of Designed House**](#side)|
| 3 | [**Back View of Designed House**](#side) |
|4  | [**Isometric View of Designed House**](#isometric)|
|5| [**Components Label**](#component)|
|6| [**Wiring Diagram**](#wiring)|

| S.No.|abbreviation | Stands For |
|:-:|:-:|:-:|
|1|**CAD**| Computer Aided Design |
|2|**MC4**| Multi-Contact 4 millimetre|
|3| **AC**| Alternating Current|
|4| **DC**| Direct Current|
|5| **MCB** | Miniature Circuit Breaker| 
---

## 3.1 CAD/Assembly
The following image is the 3-D diagram of the designed house.
<p align="center">
	Front View
	<figcaption align="center">Fig 3.1.1: Front View</figcaption>
</p>

<p align="center">
	Side view 
	 <figcaption align="center">Fig 3.1.2: Side View</figcaption>
</p>

<p align="center">
	 Top View
	 <figcaption align="center">Fig 3.1.3: Top View</figcaption>
</p>

<p align="center">
	 Isometric view 
	 <figcaption align="center">Fig 3.1.3: Orthographic View</figcaption>
</p>

The components of our energy solution are detailed as follows:

***Label 1*** - Solar Panels
Solar panels to take the solar energy and give a DC current.

<p align="center">
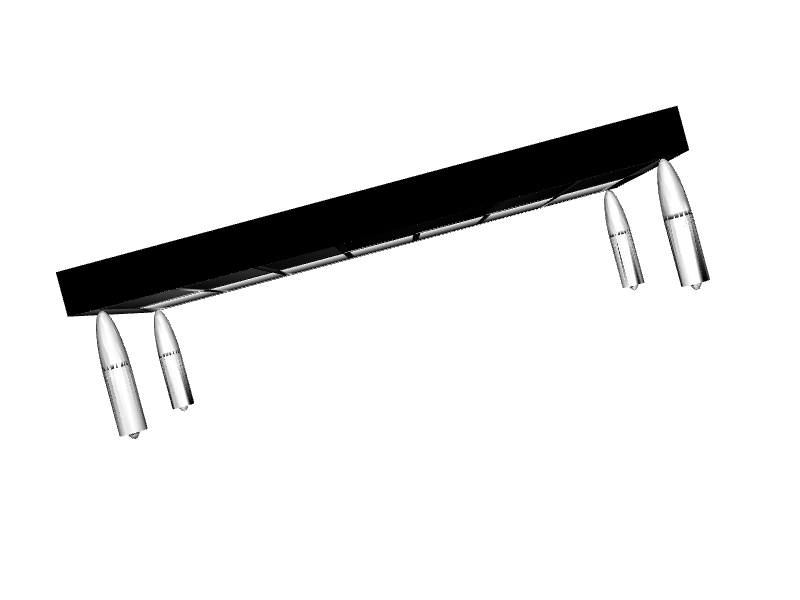
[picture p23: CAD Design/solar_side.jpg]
Side view
	 
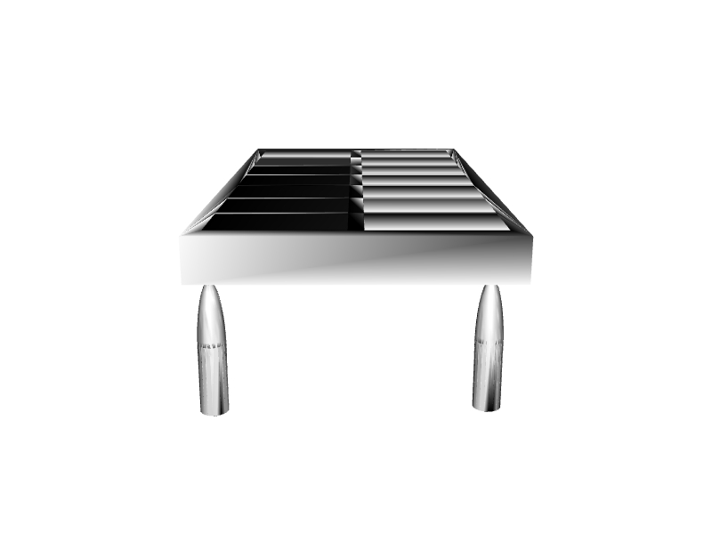
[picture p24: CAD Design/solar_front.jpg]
Front View
	
	Top View
	<figcaption align="center">Fig 3.1.4: Side View, Front View and Top View (L to R)</figcaption>
</p>

***Label 2*** - Inverter  
Takes the solar DC current, and supply it power supply as well as store it in battery.

<p align="center">
	Side view 
	Front View
	Top View
	<figcaption align="center">Fig 3.1.5: Side View, Front View and Top View (L to R)</figcaption>
</p>

***Label 3*** - Battery  
Stores the solar converted electrical energy for further use when solar power cannot be harnessed e.g. Night. 

<p align="center">
	Side view 
	Front View
	Top View
	<figcaption align="center">Fig 3.1.5: Side View, Front View and Top View (L to R)</figcaption>
</p>

---

## 3.2 Wiring Diagram
The next step is to realize the design using all the components mentioned in the specifications by appropriately connecting them. The diagram below shows the connections for the same. 



The solar panels are connected in a 2x2 fashion using the MC4 Panel Connectors. These are then connected to a DC Circuit Breaker using T4 connectors. The wires then go via a DC Surge Protector to the invertor which is connected to a series combination of 3 batteries of 12V each. The output of the invertor then goes to an AC circuit breaker which has also been connected to the generator for backup. This is finally connected to the MCB inside the house.

---

## 3.3 Documentation Statistics

| Word Count | # unique words | # repeated words | # sentences | # characters | # characters w/o spaces | # syllables |
|---|---|---|---|---|---|---|
| 434 | 922 | 1715 | 11 | 3592 | 3204 | 941 |

| Avg # words per sentence | Avg # characters per sentence | Avg # characters per word | Avg # syllables per word |
|---|---|---|---|
| 40 | 327 | 7.4 | 2.16 |

The above results were obtained using https://wordcounter.net/ [7].

---

## 3.4 Document Readability indices

| Readability Index | Score |
|---|---|
| Flesch Reading Ease score | 61 |
| Dale-Chall Readability score | 8.8 |
| Flesch-Kincaid Grade level | 7 |
| The Coleman-Liau Index | 14 |
| Automated Readability Index | 11 |
| SMOG Formula score | 12 |
| Spache Readability score | 4 |

The above scores were obtained using Visual Studio Code extension called Readability Check [8] by jemcclin.

---

## 3.5 References

[1] [GitHub - Off Grid Energy Design - Tribe E](https://github.com/CrypticPoet/off-grid-energy-design)

[2] [600 Watt Solar Panel Wiring Diagram & Kit List](https://mowgli-adventures.com/600-watt-solar-panel-wiring-diagram/)

[3] [Application of  DC600V/20kA Photovoltaic Surge Protector for Solar Power System/PV Solar SPD](https://sc01.alicdn.com/kf/HTB1CF0DHFXXXXaiXXXXq6xXFXXXB/201135244/HTB1CF0DHFXXXXaiXXXXq6xXFXXXB.jpg_.webp)

[4] [Factory Customized High Efficient T4 Solar Connector](https://image.made-in-china.com/44f3j00sfSTKWnPEyrL/Dsola-Factory-Customized-High-Efficient-T4-Solar-Connector.jpg)

[5] [How to Connect a Portable Generator to the Home Supply - 4 Methods](https://www.electricaltechnology.org/2013/11/how-to-connect-portable-generator-to-home-supply.html)

[6] [Solarverter PRO PCU Installation | Luminous India](https://www.youtube.com/watch?v=BmDQkVR5orU)

[7] [WordCounter - Count Words & Correct Writing](https://wordcounter.net/)

[8] [Readability Check - Visual Studio Marketplace](https://marketplace.visualstudio.com/items?itemName=jemcclin.readabilitycheck)

---

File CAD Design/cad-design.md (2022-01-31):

## 3.1 CAD/Assembly
The following image is the 3-D diagram of the designed house.
<p align="center">
	Front View
	<figcaption align="center">Fig 3.1.1: Front View</figcaption>
</p>

<p align="center">
	Side view 
	 <figcaption align="center">Fig 3.1.2: Side View</figcaption>
</p>

<p align="center">
	 Top View
	 <figcaption align="center">Fig 3.1.3: Top View</figcaption>
</p>

<p align="center">
	 Isometric view 
	 <figcaption align="center">Fig 3.1.3: Orthographic View</figcaption>
</p>

The components of our energy solution are detailed as follows:

***Label 1*** - Solar Panels
Solar panels to take the solar energy and give a DC current.

<p align="center">
	Side view 
	Front View
	Top View
	<figcaption align="center">Fig 3.1.4: Side View, Front View and Top View (L to R)</figcaption>
</p>

***Label 2*** - Inverter  
Takes the solar DC current, and supply it power supply as well as store it in battery.

<p align="center">
	Side view 
	Front View
	Top View
	<figcaption align="center">Fig 3.1.5: Side View, Front View and Top View (L to R)</figcaption>
</p>

***Label 3*** - Battery  
Stores the solar converted electrical energy for further use when solar power cannot be harnessed e.g. Night. 

<p align="center">
	Side view 
	Front View
	Top View
	<figcaption align="center">Fig 3.1.5: Side View, Front View and Top View (L to R)</figcaption>
</p>

---

## 3.2 Wiring Diagram
The next step is to realize the design using all the components mentioned in the specifications by appropriately connecting them. The diagram below shows the connections for the same. 



The solar panels are connected in a 2x2 fashion using the MC4 Panel Connectors. These are then connected to a DC Circuit Breaker using T4 connectors. The wires then go via a DC Surge Protector to the invertor which is connected to a series combination of 3 batteries of 12V each. The output of the invertor then goes to an AC circuit breaker which has also been connected to the generator for backup. This is finally connected to the MCB inside the house.

---

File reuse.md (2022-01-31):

#REUSE OF MATERIALS

1) Solar Panels 

    - Create Greenhouses : A greenhouse is generally made up of glass and so are solar panels. We can easily make use of them and keep our plants warm throughout the cooler months. The junction box and frame are separately removed to recover copper and aluminum. Both of these materials are 100% reusable.
    
    - Use Them as Insulation : We can use our old solar panels to create walls and insulation to make our home even more eco friendly.
    
2) Battery 

    - Solar Powered Generator : We can make a solar powered generator using old or dead batteries and this could be sufficient for 25 hours if we use energy saving bulbs.
    
    - A Portable Rechargeable Lighting System : We can make portable rechargeable lighting systems using old or dead batteries. All we need is – LED plate, On/off switch, Diode IN4007, 1000 Ohms Resistor, Red LED light, Charging socket, Superglue, Soldering tool.

3) Mounting apparatus

    - These are structures made of galvanized iron and can be used for mounting other solar panels or can also be sold as scrap iron to manufacture other equipment.

4) Backup Generator

    - Generator is always needed for family reunions, weddings, cookouts and other outdoor parties to provide power.
    
    - Generators can be used to store the energy captured by solar panels to be used later instead of sending it back to the grid.

5) Disconnects
    
    - Circuit breaker is reusable and can be reset after it has tripped due to overloads.

6) Inverter
    
    - The DC electricity generated by the solar panels is converted into AC using this inverter, for powering all electrical appliances, lighting, power tools etc. in the house.

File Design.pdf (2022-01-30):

# ELP305 Design and Systems Laboratory

# Semester 2, 2021-2022

### Tribe E

# 3. SUNERGY Design

The GitHub repository that our tribe is using is linked here (https://github.com/CrypticPoet/off-grid-energy-design) [1].

In the following document, we give a brief on how the off-grid energy solution is expected to look like after assembling the various components. We also give design blueprints and wiring diagrams wherever required, making necessary but plausible assumptions about the geography and architecture of the house.

NOTE: Some specifications have been changed after taking the design into consideration. These updated requirements/specifications are available in the GitHub repository.

Table of Contents:

3. SUNERGY Design
3.1 CAD/Assembly
3.2 Wiring Diagram
3.3 Documentation Statistics 3.4 Document Readability indices 3.5 References

# 3.1 CAD/Assembly

The following image is the 3-D diagram of the designed house.


Fig 3.1.1: Front View


Fig 3.1.2: Side View and Back View (L to R)


Fig 3.1.3: Isometric View

The components of our energy solution are detailed as follows:


Fig 3.1.4: Component Labels

Label 1 - Solar Panels
Solar panels to take the solar energy and give a DC current.

Label 2 - Inverter
Takes the solar DC current and supply it power supply as well as store it in battery.

Label 3 - Battery
Stores the solar converted electrical energy for further use when solar power cannot be harnessed e.g. Night.

# 3.2 Wiring Diagram

The next step is to realize the design using all the components mentioned in the specifications by appropriately connecting them. The diagram below shows the connections for the same.


The solar panels are connected in a 2x2 fashion using the MC4 Panel Connectors. These are then connected to a DC Circuit Breaker using T4 connectors. The wires then go via a DC Surge Protector to the invertor which is connected to a series combination of 3 batteries of 12V each. The output of the invertor then goes to an AC circuit breaker which has also been connected to the generator for backup. This is finally connected to the MCB inside the house.

# 3.3 Documentation Statistics

Word Count | # unique words | # repeated words | # sentences | # characters | # characters w/o spaces | # syllables
434 | 922 | 1715 | 11 | 3592 | 3204 | 941
Avg # words per sentence | Avg # characters per sentence | Avg # characters per word | Avg # syllables per word
40 | 327 | 7.4 | 2.16

The above results were obtained using https://wordcounter.net/ [7].

# 3.4 Document Readability indices

Readability Index | Score
Flesch Reading Ease score | 61

Readability Index | Score
Dale-Chall Readability score | 8.8
Flesch-Kincaid Grade level | 7
The Coleman-Liau Index | 14
Automated Readability Index | 11
SMOG Formula score | 12
Spache Readability score | 4

The above scores were obtained using Visual Studio Code extension called Readability Check [8] by jemcclin.

# 3.5 References

[1] GitHub - Off Grid Energy Design - Tribe E (https://github.com/CrypticPoet/off-grid-energy-design)
[2] 600 Watt Solar Panel Wiring Diagram & Kit List (https://mowgli-adventures.com/600-watt-solar-panel-wiring-diagram/)
[3] Application of DC600V/20kA Photovoltaic Surge Protector for Solar Power System/PV Solar SPD (https://sc01.alicdn.com/kf/HTB1CF0DHFXXXXaiXXXXq6xXFXXXB/201135244/HTB1CF0DHFXXXXaiXXXXq6xXFXXXB.jpg_.webp)
[4] Factory Customized High Efficient T4 Solar Connector (https://image.made-in-china.com/44f3j00sfSTKWnPEyrL/Dsola-Factory-Customized-High-Efficient-T4-Solar-Connector.jpg)
[5] How to Connect a Portable Generator to the Home Supply - 4 Methods (https://www.electricaltechnology.org/2013/11/how-to-connect-portable-generator-to-home-supply.html)
[6] Solarverter PRO PCU Installation | Luminous India (https://www.youtube.com/watch?v=BmDQkVR5orU)
[7] WordCounter - Count Words & Correct Writing (https://wordcounter.net/)
[8] Readability Check - Visual Studio Marketplace (https://marketplace.visualstudio.com/items?itemName=jemcclin.readabilitycheck)

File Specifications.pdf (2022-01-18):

Specifications.md | 1/19/2022

# ELP305 Design and Systems Laboratory

### Semester 2, 2021-2022

Tribe E

# 2. SUNERGY Specifications

The GitHub repository that our tribe is using is linked here (https://github.com/CrypticPoet/off-grid-energy-design) [1].

In the following document, we give a brief on various specifications of the components that we will be using in our off-grid living solution. We also mention their properties and why we have chosen them along with the best quotation available for each component.

NOTE: These specifications may change as the design work progresses further.

2. SUNERGY Specifications
2.1 Electrical Specifications 2.1.1 Battery
Luminous Red Charge RC 25000 200 Ah battery 2.1.2 Backup Generator
2.1.3 Hybrid Solar Inverter (Built in Solar Charge Controller) 5KVA/ 48 V off Grid Solar Inverter
Solar Charge Controller
Sizing
Required Ratings
2.1.4 High Efficiency Solar Panels 2.1.5 Wires
Solar DC Cable
Household connection wires 2.1.6 Safety Measures
AC Circuit Breaker
DC Circuit Breaker
DC Surge Protection Device Porcelain Fuse
2.1.7 MC4 Connectors
MC4 Solar Panel Connectors 4 in 1 T4 Connector
2.2 Mechanical Specifications
2.2.1 Solar Panel Mounts
2.2.2 Prefabricated portable Biogas Plant 2.3 Documentation Statistics [2]
2.4 Document Readability indices [3]
2.5 References

## 2.1 Electrical Specifications

2.1.1 Battery

Luminous Red Charge RC 25000 200 Ah battery

For heavy-duty application with excellent overcharge tolerance, superior performance during long frequent power cuts, and minimum maintenance
Fast battery charging with adaptive battery charging control technology to prevent overcharging

We select a battery bank such that we can ensure ample power for upto 24 hours. For this, a suitable choice is 4 batteries of 12V, 200 Ah rating connected in series.


Specifications | Value
Brand | Luminous
Nominal Voltage | 12V
Rated Capacity(at room temp.) | 200 ah
Protections | Dust & water proof with heavy plastic body
Charging Current(Boost mode) | 20.2A(starting), 10.1A(finishing)

Charging Current (Trickle mode) 672 mA(max), 168 mA(min)

Weight | 60 Kg (34.4 Kg dry weight)
Dimensions | 50.2 X 44 X 19.1 cm (L X W X H)
Electrolyte Volume | 19.9L
Water Level Indicators | 6
Cost | ₹14,780 X 4 = ₹59120

Product Link (https://www.amazon.in/dp/B07BCDDXZJ/ref=cm_sw_r_apan_glt_i_J1N15MKV18TN69RT1Q67?_encoding=UTF8&psc=1)

2.1.2 Backup Generator

The generator size should be of 3kW. In our system, generator will mostly be needed during winter when there is a lack of solar energy production. So the power calculation will be done under winter conditions. And since this is a backup system the below power consumed is assumed to be calculated under maximum load when running backup generator.

Total Instantaneous Power Consumed = 0.036*4(light)+1.5(house heater)+0.15(fridge)+1(misc.) = 2.8kW

Note: Here the misc. includes TV,PC, and other appliances that we might/might not use under emergency situation. The generator should be able to run under the above conditions for 12hr. Spare fuel should always be kept in case of emergencies.


Specification | Value
Manufacturer | Techno Machineries
Fuel | Kerosene(Run), Petrol (Start)
Consumption | 1L/hr under full load
Capacity | 12L
Rated voltage | 220V+-15

Rated output power 2.8kW

Peak output power | 3kW
Weight | 40kg
Dimensions | 630x500x600mm
Cost | ₹32,900

Product Link (https://www.indiamart.com/proddetail/portable-generators-3kw-22423030173.html)

2.1.3 Hybrid Solar Inverter (Built in Solar Charge Controller)

5KVA/ 48 V off Grid Solar Inverter


FlinFuzion Solar Hybrid Inverter 5kVA/48V is an off grid hybrid solar inverter which supports lead acid and lithium batteries both. It comes built in with an mppt technology based Solar Charge Controller that converts solar energy into electricity and stores power.

Off grid hybrid solar inverter with lithium battery / Lead acid battery support functionality.
5 kva system with 5000 watt solar panel support
super efficient as low conversion loss from battery
LCD Battery Monitoring system with display parameters such as Input Power, Output power load, battery health, battery percentage
Surge warnings, safety alarms and troubleshooting Fault Codes
Included battery monitoring software with USB and RS232 Data Ports
Specification | Value
Brand | Flin Energy
Rated Power | 5kVA
Waveform | Pure sine wave
Output Voltage Regulation | 230VAC ± 5%
Output Frequency | 50 Hz
Battery Voltage | 48 VDC

Battery Overcharge protection 63 VDC

Battery Equalization | Yes
Maximum AC Charge Current | 60 A

Specification | Value
Peak Efficiency | 93%
Overload Protection | 5s@≥150% load; 10s@110%~150% load
Surge Capacity | 10kVA for 5 seconds
No Load Power Consumption | <35W
Dimensions | D x W x H (mm) 100 x 300 x 440
Net Weight | 10 kg
Cost | ₹78,800

Solar Charge Controller

Charge controllers are used to control the amount of current fed into the battery by the solar panels. This ensures the batteries are not overcharged during the day and don't leak current back to the panels during the night. So, Solar Charge Controller must be compatible with solar panel and the battery bank. Our Hybrid inverter comes built in with an MPPT Charge controller which is more efficient at DC Conversion compared to older PWM technology.

Sizing

Sizing of a controller depends on three factors

Solar panel arrayʼs maximum open-circuit voltage (Voc) Total Power rating of Solar panel array
Battery Bank Voltage

Required Ratings

Solar panel arrayʼs maximum open-circuit voltage (Voc): The 8 solar panels are arranged in a 2x4 array, such that 4 pairs of solar panels are in parallel, with each pair in series. Each Solar panel has a open circuit voltage of 49V. So, the maximum open circuit voltage of solar panel is 49x2= 98V.

Total Power rating of Solar panel array: Since, we are using 8 solar panels with 440 W power rating.Hence, the total power rating of Solar panel array is 3520W.

Battery Bank Voltage: Battery Bank Volatge of our system is 48V.

Now, from power rating and battery bank voltage, we can calculate the required Ampere rating of the controller, which is equal to (power rating/Bank Voltage). So, the required Ampere rating is 73.33A. The required maximum input Voc of controller = maximum open circuit voltage of solar panel.

Hence, Our Controller must have atleast 98V input Voc rating and 73.33A current rating. We select the controller such that these two figures slightly exceed the requirements to build a safety margin.

Specifications of the in-built charge controller

Specification | Value
Brand | Flin Energy
Type | MPPT

Maximum Solar Charging Current 80A

Maximum PV Array Power | 5 kW
Operating Voltage Range | 120-450V
Nominal PV Voltage | 240V
Maximum PV VOC | 500V

Product Link (https://www.amazon.in/Flin-Energy-FlinFuzion-Hybrid-Inverter/dp/B0793KN2K8/)

2.1.4 High Efficiency Solar Panels

Solar panels collect clean renewable energy in the form of sunlight and convert that light into electricity which can then be used to provide power for electrical loads.

The panels which we're using, are based on mono PERC cells, (https://regenpower.com/news/why-choose-mono-perc-panels-rooftop-solar/) which results into higher electricity generation due to higher light absorption per unit area, when compared to traditional panels.

It also paves the way for more power output per panel, which means less number of panels are required for a given power requirement. It means less expenditure for panel mounts. (https://encrypted-tbn0.gstatic.com/images?q=tbn:ANd9GcSWhB7u8DxJiUJTM2uH5U-6Ml3h3SoByqJd8g&usqp=CAU)


We'll be using 8 such panels in our system.

Specification (Single panel) | Value
Cost | ₹20,000
Operating Voltage | 24V
Dimensions | 6.9ft X 3.4ft
Manufacturer | Loom Solar
Rated Output Power (Peak) | 440W

Output Voltage at max. power 42V

Output Current at max. power 10.5A

Above electrical data is for, Irradiance: 1000W/m² and Cell Temperature:25°C

Product Link (https://www.loomsolar.com/products/loom-solar-panel-shark-super-high-efficiency-module)

2.1.5 Wires

Solar DC Cable

DC Solar Panel cables are required to connect the array of solar panels in series with each other and then carry the output DC Current to the Solar Charge Controller.

When choosing DC Solar Panel wires, some things should be kept in mind

The wires should be of sufficient diameter to ensure that no overheating occurs The wires should be of adequate current rating
UV resistance to ensure longevity


Specification | Value
Brand | Microtek
Current carrying capacity | 80 A
Cross Sectional Area | 10 mm²
Length | 15m Red and 15m Black
Cost | ₹1990

Product Link (https://www.amazon.in/Microtek-Solar-Cable-Protected-15Meter/dp/B08BBYX28X/)

Household connection wires

Connecting wires would be used to connect different appliances in the energy grid. Hence they should be able to carry high current and be well insulated.


Specification | Value
Brand | Havells
Length | 90 m
Cross-sectional area | 2.5 sq mm
Current carrying capacity | 28 A
Voltage Grade | 1100 V
Insulation material | HRFR PV
Conductor material | ETP Grade Annealed Copper
Cost | ₹2,871
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

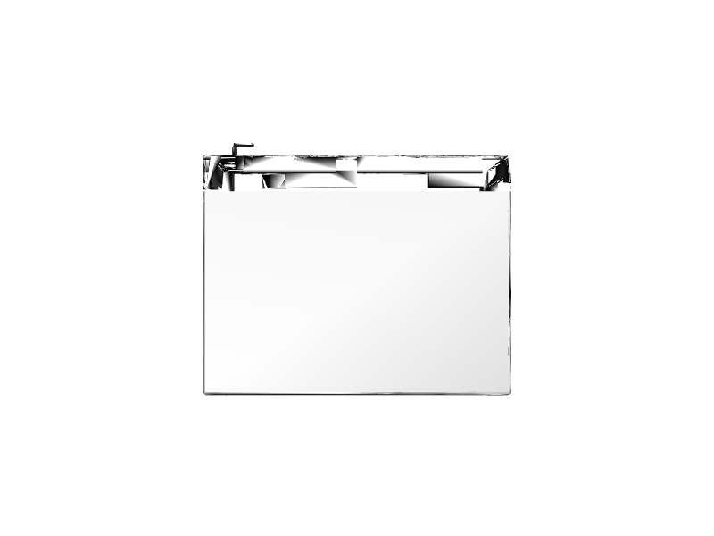
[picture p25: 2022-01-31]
CAD Design/battery_front.jpg

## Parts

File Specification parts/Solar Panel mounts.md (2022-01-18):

### Solar Panel Mounts

Panel mounts are used to fix solar panels on surfaces like roofs, building facades, or ground. The panel array is mounted with each panel aligned at an angle. This angle is variable and mounts should be bought according to the type of rooftop. We'll be using ones with 25° inclination.



We'll be using 2 such mounts for our system, which consists of 8 panels.

| Specification  (Single unit)  |  Value |
| --- | --- |
| Cost | &#8377 12,000 |
| Inclination | 25° |
| Dimensions(Leg) | 150cm $\times$ 60cm |
| Manufacturer | Loom Solar |
| Weight | 50kg |
| Material | Galvanised Iron |
| Holding Capacity | 4 Panels |
Data [Source](https://www.loomsolar.com/collections/solar-panel-stand/products/loom-solar-2-row-design-4-panel-stand-375-watt)
<!--  
https://www.loomsolar.com/collections/solar-panel-stand/products/loom-solar-2-row-design-4-panel-stand-375-watt-->

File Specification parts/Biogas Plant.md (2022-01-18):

### Prefabricated portable Biogas Plant

With a biogas plant, organic waste and side streams are converted into income by producing renewable energy and organic fertilizer cost-effectively. Produced biogas can be utilized for electricity and heat production. Biogas can be also upgraded to biomethane that can be used as vehicle fuel or fed into the natural gas grid as a substitute for fossil gas.



| Specification | Value |
| --- | --- |
| Cost | Rs. 23,599 |
| Plant Capacity | 2 $m^{3}$ |
| Area to be covered | 3m $\times$ 3m |
| Company | Gujarat Renewable Energia |
| Body Material | PVC Coated Fabric |
| Shape | Round |
| Color | Gray |

[Product Link](https://www.indiamart.com/proddetail/flexible-biogas-plant-21839483148.html)

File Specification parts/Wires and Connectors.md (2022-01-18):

## Wires
### Solar DC Cable
DC Solar Panel cables are required to connect the array of solar panels in series with each other and then carry the output DC Current to the Solar Charge Controller.

When choosing DC Solar Panel wires, some things should be kept in mind
- The wires should be of sufficient diameter to ensure that no overheating occurs
- The wires should be of adequate current rating
- UV resistance to ensure longevity



| Specification | Value |
| --- | --- |
| Brand | Microtek |
| Current carrying capacity | 80 A |
| Cross Sectional Area | 10 $mm^2$ |
| Length | 15$m$ Red and 15$m$ Black |
| Cost | Rs. 1990 |

[Product Link](https://www.amazon.in/Microtek-Solar-Cable-Protected-15Meter/dp/B08BBYX28X/)

### Household connection wires
Connecting wires would be used to connect different appliances in the energy grid.  Hence they should be able to carry high current and be well insulated.

connecting wires

| Specification | Value |
| --- | --- |
| Brand | Havells |
| Length | 90 m |
| Cross-sectional area | 2.5 sq mm |
| Current carrying capacity | 28 A |
| Voltage Grade | 1100 V |
| Insulation material | HRFR PV |
| Conductor material | ETP Grade Annealed Copper |
| Cost | Rs. 2,871 |

[Product Link](http://dl.flipkart.com/dl/havells-hrfr-pvc-2-5-sq-mm-black-90-m-wire/p/itmbcd2c1b016975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)

---

## MC4 Connectors
### MC4 Solar Panel Connectors

MC4 Connectors are required for a safe and convenient connection between the solar panel arrays.   
The Kenbrook Solar MC4 Connectors are UV resistant, waterproof and anti-flame boasting an estimated life of upto 25 years and thus require minimum maintenance.



| Specification | Value |
| --- | --- |
| Brand | Kenbrook |
| Material | Copper (Tin Plated) \| PPO + PA (Outer Covering) |
| Dimensions | 6 x 4 x 2 $cm$ |
| Quantity | 10 Male + Female MC4 Connectors |
| Cost | Rs. 449 |

[Product Link](https://www.amazon.in/Kenbrook-Solar-Connector-Panel-Connection/dp/B08VNW7DLP/)

### 4 in 1 T4 Connector

T4 Connector is required to connect the 2x4 parallel solar panel array to the solar charge controller. The T4 connector also comes with UV Resistance, anti flame and water resistance



| Specification | Value |
| --- | --- |
| Brand | Kenbrook |
| Material | Copper (Tin Plated) \| PPO + PA (Outer Covering) |
| Dimension | 17 x 17 x 2 $cm$ |
| Quantity | 2 sets |
| Cost | Rs. 799 |

[Product Link](https://www.amazon.in/Kenbrook-Solar-T4-Connector-Support/dp/)

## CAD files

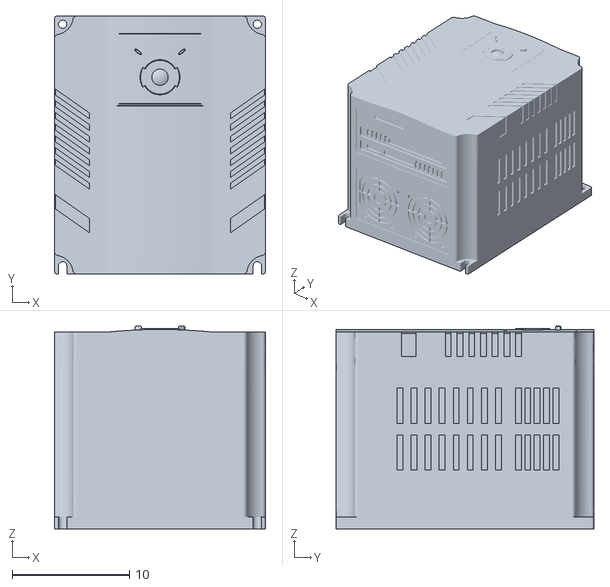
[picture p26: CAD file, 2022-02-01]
CAD Design/Inverter.STL
18.0 x 22.0 x 17.3

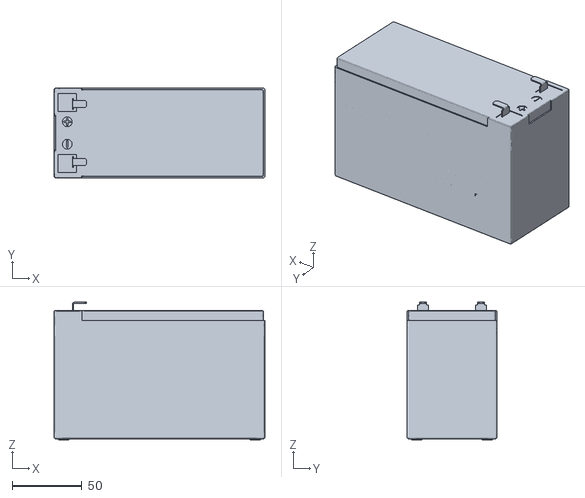
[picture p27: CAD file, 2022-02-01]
CAD Design/Battery.stl
151.0 x 64.5 x 98.5

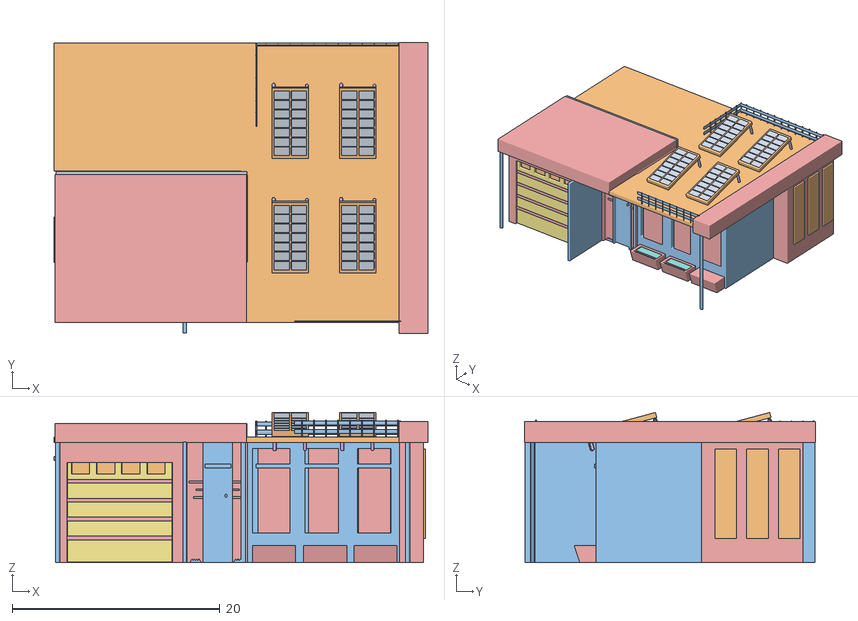
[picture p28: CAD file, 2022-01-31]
CAD Design/home.obj
36.0 x 28.0 x 14.4

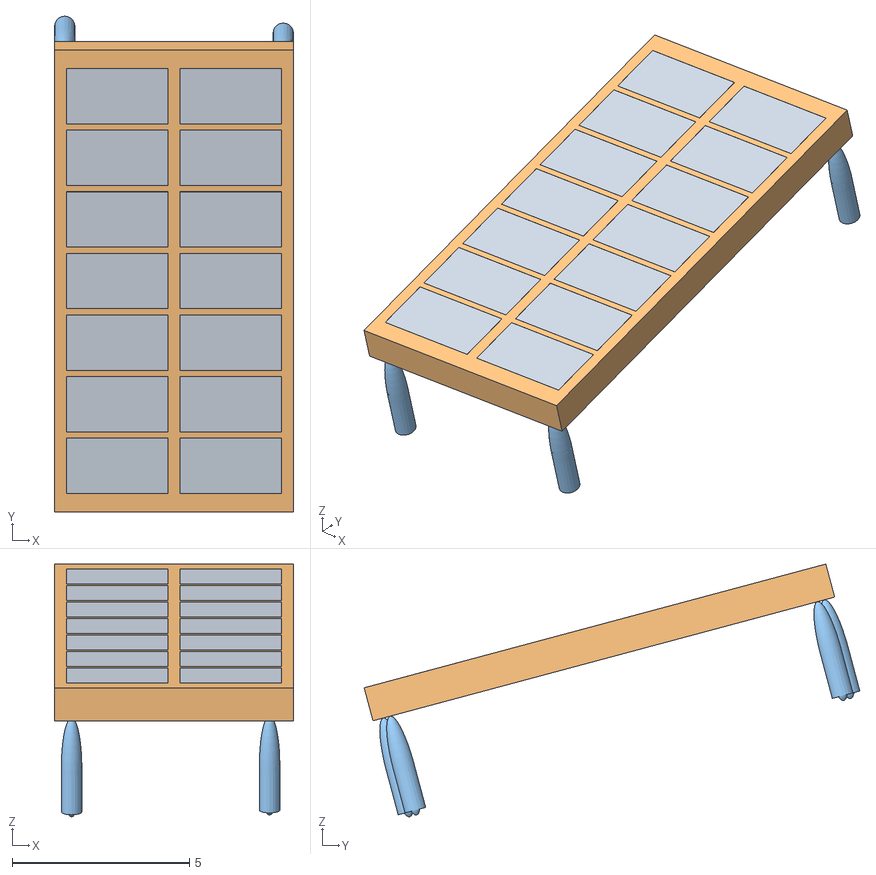
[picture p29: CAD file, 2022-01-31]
CAD Design/solar.obj
6.75 x 14.0 x 7.14

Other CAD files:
CAD Design/battery.obj
CAD Design/inverter.obj

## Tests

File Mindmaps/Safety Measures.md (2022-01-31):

###  Anchor by Panasonic 99004 UNO (6kA) 20 Ampere C Curve Single Pole MCB



| Specification  | Value |
| --- | --- |
| Cost |&#8377 167 |
| Dimensions | 415mm $\times$ 375mm $\times$ 225mm|
| Current Rating | 20 A |
| Material |  Polycarbonate |
| Color| White|

<!--- https://www.amazon.in/Anchor-Panasonic-99004-Ampere-Single/dp/B086HBKRJG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 --->
 
 ###  Siemens Plastic 63A 4 Pole MCB
 

| Specification  | Value |
| --- | --- |
| Cost |&#8377 1500 |
| Dimensions | 7.1 cm $\times$ 7 cm $\times$ 9 cm|
|Weight|660 g|
| Current Rating | 63 A|
| Material |  Polycarbonate |
| Color| White|
 
 <!--- https://www.amazon.in/Siemens-Pole-White-1-Piece-5SL64637RC/dp/B01D4QL6RC--->

###   Anchor 9311 Porcelain Fuse Unit Pilot



|Specification| Value|
|---|---|
|Cost| &#8377 185|
|AC Adapter Current|32 A|
|Voltage|415 V|
|Material|Ceramic|
|Dimensions|10 cm $\times$ 5 cm $\times$ 5 cm|

<!--- https://www.amazon.in/Anchor-9311-Porcelain-Pilot-Ivory/dp/B00V4VJ7IK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>

### FEEO Plastic 63A Double Pole DC MCB



|Specification| Value|
|---|---|
|Cost| &#8377 999|
|Current Rating|63 A|
|Voltage|800 V (DC)|
|Dimensions|7.1 cm $\times$ 3.6 cm $\times$ 8 cm|
|Circuit Breaker Type|Standard|

<!--- https://www.amazon.in/FEEO-63A-Double-Pole-MCB/dp/B01LF8E0T2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>

### Kenbrook Solar Elmak DC SPD 600V 2 Pole Surge Protection Device



|Specification|Value|
|---|---|
|Cost |&#8377 799|
|Dimension |9 cm $\times$ 6 cm $\times$ 3.5 cm|
|Weight| 245 g|

<!--- https://www.amazon.in/Kenbrook-Solar-Elmak-Protection-Device/dp/B09NTQDJGP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>

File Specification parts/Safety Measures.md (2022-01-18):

 ###  AC Circuit Breaker
 
 A separate AC Breaker between the AC Input and Inverter is required to ensure tha the inverter can be securely disconnected during maintenance and secured from AC Input over current

 

| Specification  | Value |
| --- | --- |
| Brand | Siemens |
| Current Rating | 63 A |
| No. of Poles | 4 |
| Dimensions | 7.1 cm $\times$ 7 cm $\times$ 9 cm |
| Weight | 660 g |
| Material | Polycarbonate |
| Color | White |
| Cost | &#8377 1500 |
 
 <!--- https://www.amazon.in/Siemens-Pole-White-1-Piece-5SL64637RC/dp/B01D4QL6RC--->

### DC Circuit Breaker

A DC Circuit breaker between the Solar Panels and Inverter is required for disconnecting the solar panels safely for maintenance or replacement. The Circuit breaker also protects the inverter from over current damage



| Specification | Value |
| --- | --- |
| Brand | FEEO |
| Circuit Breaker Type | Standard |
| Current Rating | 63 A |
| No. of Poles | 2 |
| Voltage | 800 V (DC) |
| Dimensions | 7.1 cm $\times$ 3.6 cm $\times$ 8 cm |
| Cost | &#8377 999 |

<!--- https://www.amazon.in/FEEO-63A-Double-Pole-MCB/dp/B01LF8E0T2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>

### DC Surge Protection Device

The DC Surge Protector protects the inverter and panels from any unforeseen voltage surges in instances such as Lightning strikes



| Specification | Value |
| --- | --- |
| Brand | Kenbrook Solar |
| Overvoltage Rating | 600V |
| No. of Poles | 2 |
| Dimension | 9 cm $\times$ 6 cm $\times$ 3.5 cm |
| Weight | 245 g |
| Cost | &#8377 799 |

<!--- https://www.amazon.in/Kenbrook-Solar-Elmak-Protection-Device/dp/B09NTQDJGP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>

###   Porcelain Fuse



| Specification | Value |
| --- | --- |
| Brand | Anchor |
| AC Adapter Current | 32 A |
| Voltage | 415 V |
| Material | Ceramic |
| Dimensions | 10 cm $\times$ 5 cm $\times$ 5 cm |
| Cost | &#8377 185 |

<!--- https://www.amazon.in/Anchor-9311-Porcelain-Pilot-Ivory/dp/B00V4VJ7IK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>

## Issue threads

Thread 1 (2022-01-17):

Sample Issue

Mihirokte, 2022-01-17:
We will add all people who are assigned with specific tasks here, and then you will have to attach your Pull requests to respective issue. An Issue can have maximum 10 people and it's less likely we will have sub-teams of more than that. Label stands for what type of work this is e.g design, documentation etc... Milestones denote all the deadlines which SK gives to us

Prasoon1207, 2022-01-18:
[Safety Measures.md](https://github.com/CrypticPoet/off-grid-energy-design/files/7886383/Safety.Measures.md)
[Biogas Plant.md](https://github.com/CrypticPoet/off-grid-energy-design/files/7886384/Biogas.Plant.md)

TwoFourTwentyFour, 2022-01-18:
[Solar Panel mounts.md](https://github.com/CrypticPoet/off-grid-energy-design/files/7888507/Solar.Panel.mounts.md)
[Solar Panels.md](https://github.com/CrypticPoet/off-grid-energy-design/files/7888508/Solar.Panels.md)

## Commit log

2022-01-18 Create Connecting wires.md
2022-01-18 Added Battery Monitor file
2022-01-18 Updated Battery Monitor.md
2022-01-18 Added Wires and Connectors
2022-01-25 Add Wiring Diagram
2022-01-25 Added design files
    [tinker(1).obj, tinker.obj]
2022-01-25 Added CAD Design
2022-01-29 Updated mounts and link for T4 connectors
2022-01-31 Added new images
    [battery.obj, home.obj, inverter.obj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]
2022-01-31 Updated CAD model images
2022-02-01 Changes in design diagram
    [Battery.stl, Inverter.STL]
